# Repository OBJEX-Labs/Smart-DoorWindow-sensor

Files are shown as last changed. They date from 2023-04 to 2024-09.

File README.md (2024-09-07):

# Smart Door/Window sensor
The focus of this project is to prove how it is possible to drastically reduce the power consumption(in deep sleep/standby) of battery-powered smart devices by developing a customized power latch. Better design of smart devices would ensure a longer product life cycle.



## Power consumption

### Measurement range of PPK2
The current was measured with Nordic's power profiler kit , knowing that the current measured is less than the measurement range of this power profiler. I did several tests to verify the accuracy of the data. In any case the accuracy of the data, the consumption would be less than 200nA and this is a very good result considering that a similar device at a power consumption of 6-8uA.

### 1. Reed switch version
The consumption in deep sleep(POWER LATCH) is the same whether the magnet near the sensor or not.

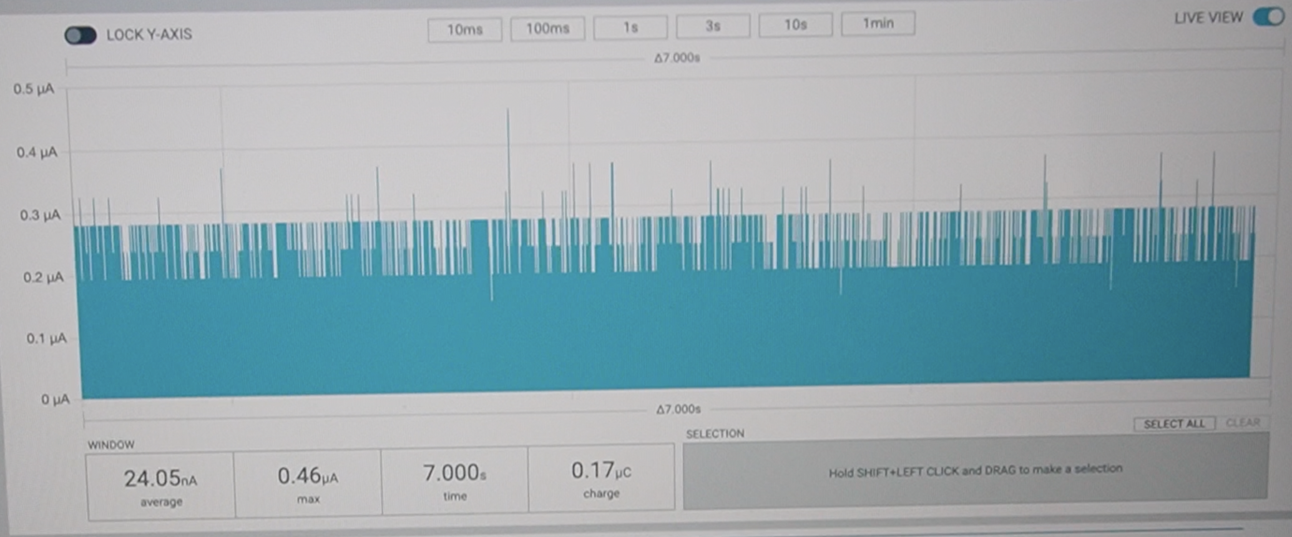
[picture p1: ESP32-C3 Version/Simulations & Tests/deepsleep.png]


### 2. MAGNETIC SENSOR IC(S-5701) version
deepsleep: 300nA

## 3D Case









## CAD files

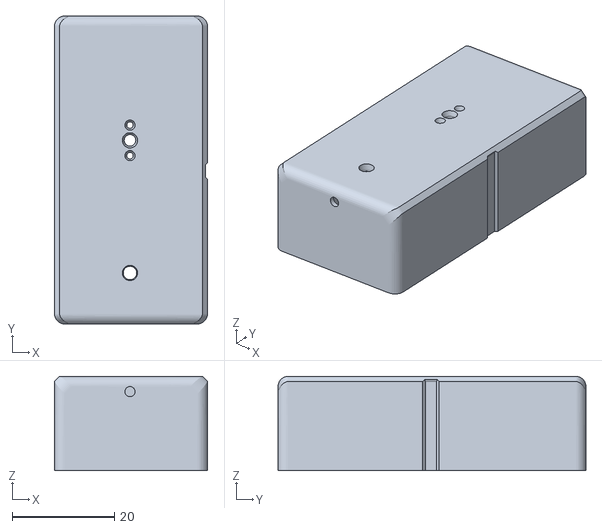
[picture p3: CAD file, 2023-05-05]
ESP32-C3 Version/3D/Outside.stl
30.0 x 60.4 x 18.5

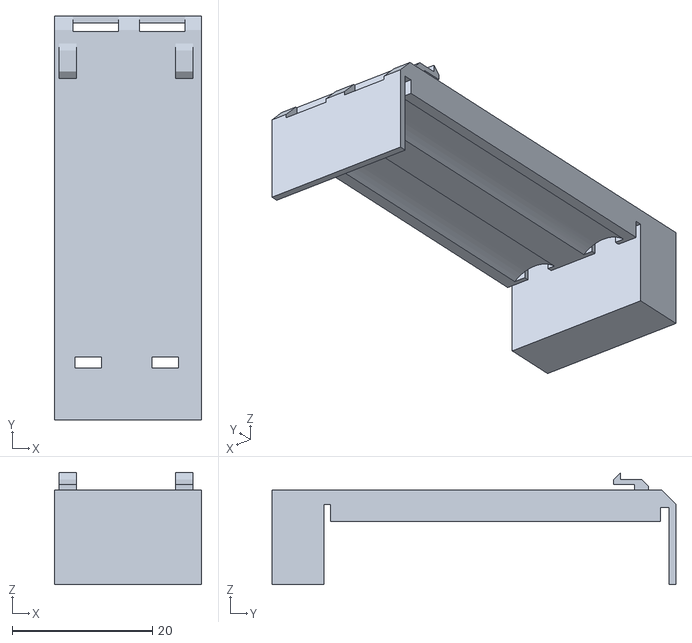
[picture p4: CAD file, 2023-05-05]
ESP32-C3 Version/3D/Inside.stl
21.0 x 57.7 x 16.0

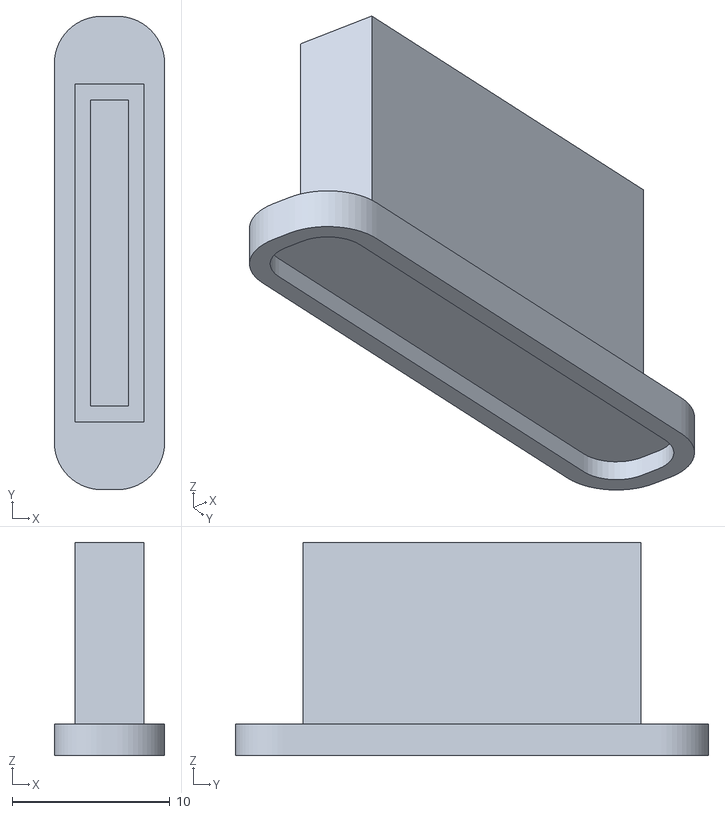
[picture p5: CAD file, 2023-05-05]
ESP32-C3 Version/3D/Bottom Magnet.stl
7.00 x 30.0 x 13.5

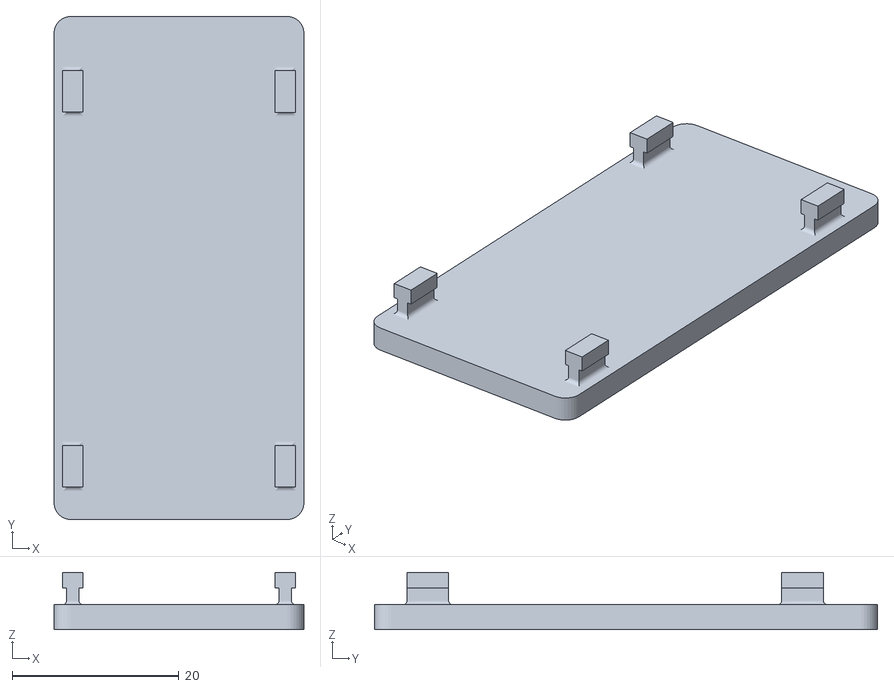
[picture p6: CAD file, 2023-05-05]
ESP32-C3 Version/3D/Bottom.stl
30.0 x 60.4 x 6.90

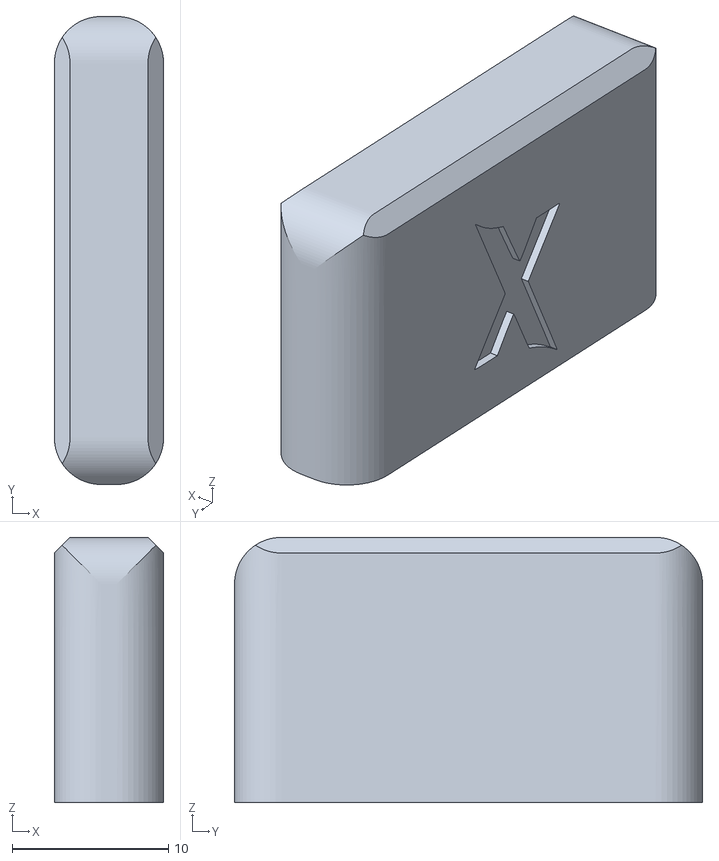
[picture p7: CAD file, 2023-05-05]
ESP32-C3 Version/3D/Magnet.stl
7.00 x 30.0 x 17.0

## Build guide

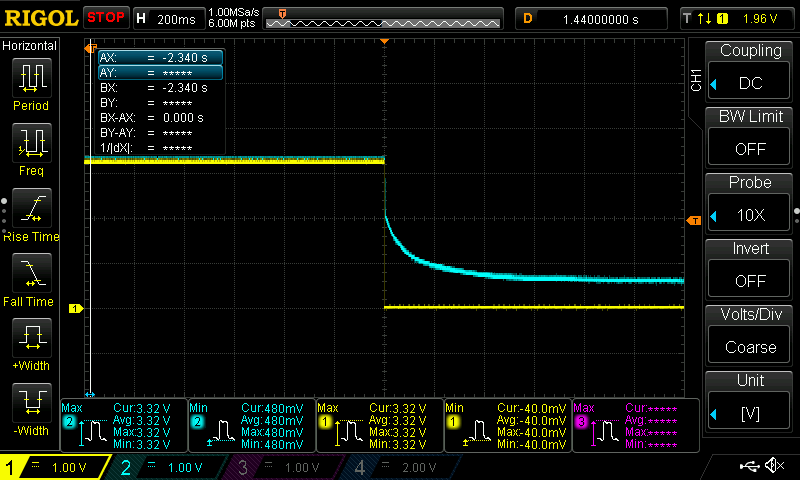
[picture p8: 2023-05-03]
ESP32-C3 Version/Simulations & Tests/DS1Z_QuickPrint24.png

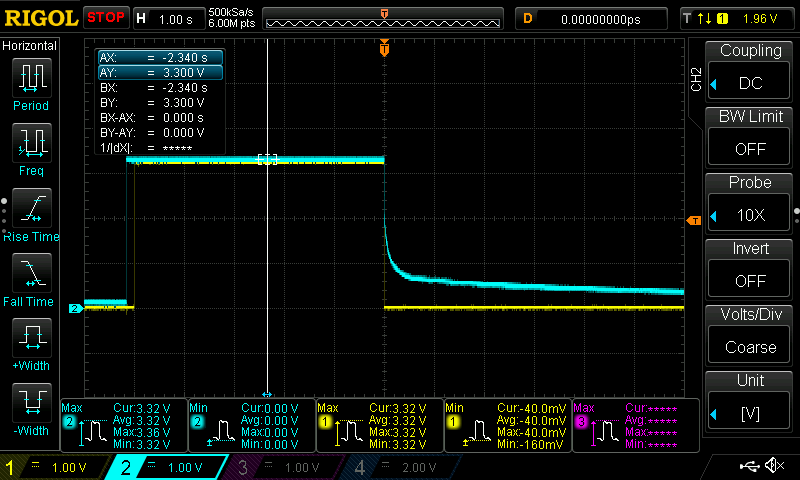
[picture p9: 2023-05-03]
ESP32-C3 Version/Simulations & Tests/DS1Z_QuickPrint27.png

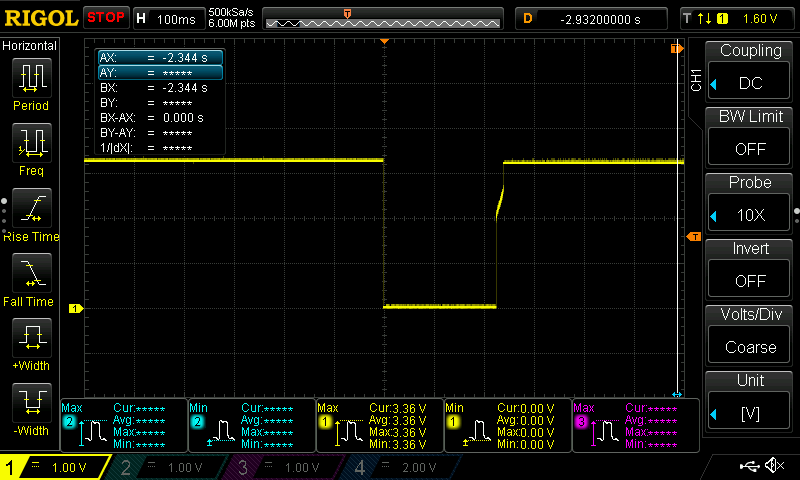
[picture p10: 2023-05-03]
ESP32-C3 Version/Simulations & Tests/DS1Z_QuickPrint20.png

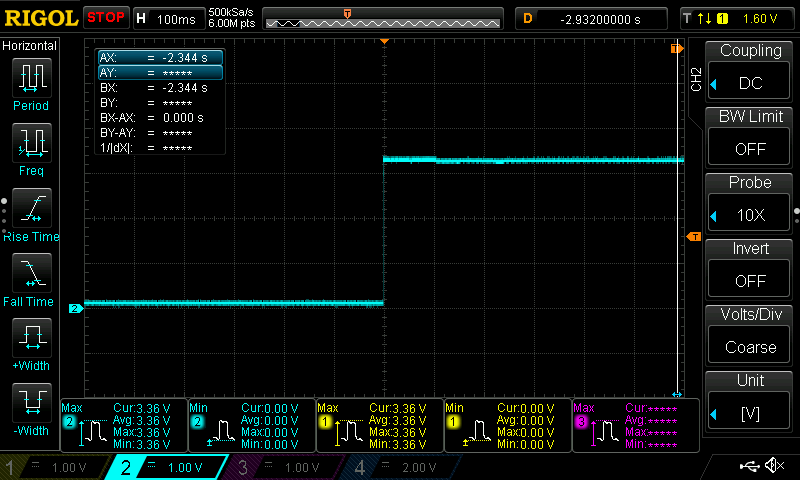
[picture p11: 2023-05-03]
ESP32-C3 Version/Simulations & Tests/DS1Z_QuickPrint21.png

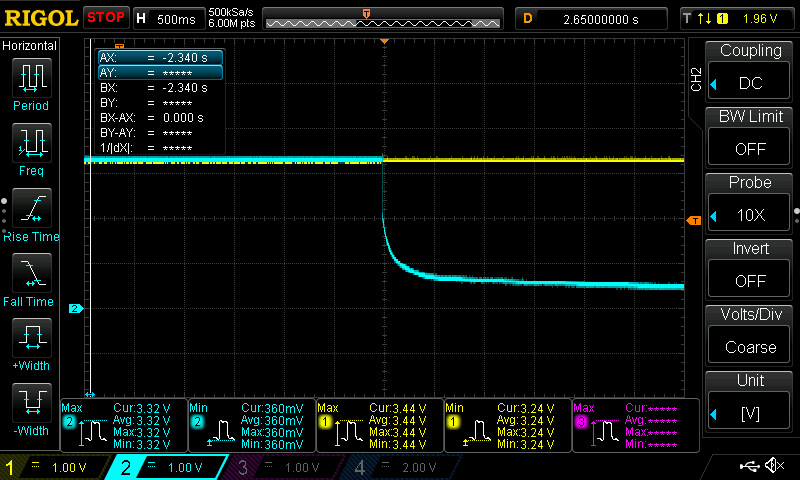
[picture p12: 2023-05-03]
ESP32-C3 Version/Simulations & Tests/DS1Z_QuickPrint22.png

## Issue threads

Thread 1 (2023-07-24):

How to add battery measurement circuit ?

Bilalembed, 2023-07-24:
Hi , can we add battery measurement circuit in this circuit to tell user the realtime battery estimation that this will take this much time. and also user should know in advance to change the battery.

Thanks

salvatoreraccardi, 2023-07-24:
There is already a circuit for measuring the battery charge level.

Closed 2023-07-24.

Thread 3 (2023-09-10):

Can Q6 and Q3 be replaced with components from other SOT-23 packaging models

zhuzhihua422619, 2023-09-10:
Can Q6 and Q3 be replaced with components from other SOT-23 packaging models? The component package you are using is too small, and which large packages can be used to replace it without affecting power consumption

salvatoreraccardi, 2023-11-19:
It depends very much on the replacement you find for the component I used.

Closed 2023-11-19.

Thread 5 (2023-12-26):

Question about Power consumption

Gafielt, 2023-12-26:
Hi Salvatore, I am very impressed by the power consumption you have achieved. I tried to understand how you got as low as 24nA, but sadly can't fully wrap my head around it. In the simulation you have provided, the numbers make sense to me (all currents for the transistors). I am only a bit sceptical about the xor chips. In the datasheet, it is said, that they would consume 10uA (which is quite a lot in your case). The resistors for detecting the switch state do also use about 400nA. Do you have any clue what I am missing or did you just had luck in the chip lottery (i guess)?

Thanks in advance! Great project!

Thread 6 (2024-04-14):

Sharing of your Smart Door / window sensor project

aeonSolutions, 2024-04-14:
Hi @salvatoreraccardi ,
great work. Been watching it on YouTube. Loved it!

Just to let you know I'm sharing your project on my own "Home automation" projects here on GitHub.
Here's the link :
[https://github.com/aeonSolutions/PCB-Prototyping-Catalogue/blob/main/Home-Automation/README.md](https://github.com/aeonSolutions/PCB-Prototyping-Catalogue/blob/main/Home-Automation/README.md)

👍

salvatoreraccardi, 2024-04-14:
Hi @aeonSolutions,
I'm glad you liked the project, that's fine for me!

aeonSolutions, 2024-04-14:
cool

since I'm here, today...

and I see you have a business as well.
On my main PCB catalog page, you can find many useful ideas on how to navigate a user from a raw repository like yours, passing by a Web interactive viewer for each PCB design and ending on an eCommerce website.

If Githuvb is your thing, I have to recommend you have a look at my "pcb catalog" and all other pages that are linked to it, here on GitHub.
Here's the direct link:

[https://github.com/aeonSolutions/PCB-Prototyping-Catalogue](https://github.com/aeonSolutions/PCB-Prototyping-Catalogue)

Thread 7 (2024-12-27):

Power the ESP directly from the NC reed switch

zorro1011, 2024-12-27:
Hi
power the ESP directly reed NC

I would like to know if there is a way to power the ESP directly using the reed NC as a simple switch.

I'm trying but it seems that the reed, once turned on (moving the magnet away), can no longer be turned off by moving the magnet closer.

I apologize if I'm OT

salvatoreraccardi, 2024-12-27:
Hi @zorro1011,
usually, it is not recommended to do this; the reed switch is not meant to have the current flowing through it to power the ESP. The idea is to use the reed switch to activate a circuit that handles the power supply to the load. I recommend you take a look at our ELPM-S3LW, you could directly connect the reed switch to the master pin. Here is a prototype we developed recently that I will show on a youtube video soon:
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

zorro1011, 2024-12-27:
thanks for answering me
the thing I don't understand is that I tried successfully to power LEDs with reed with a load greater than 200mA, but my esp32c3 that only consumes 90mA, creates problems for me with the reed

I've been fighting for days and I've tried more reeds (of the same batch and with more magnets) but without success! :-(

I thank you and I think that in the end I will have to give up and do as you say.
I was hoping that someone had succeeded

best regards

zorro1011, 2024-12-28:
Hi
for those interested, I found the problem

the esp has an electrolytic capacitor that discharges when it is not powered.
it is like a short circuit for the Reed Switch that makes the platinum points "stick".
I put a 10k resistor in parallel with the Reed that keeps the esp electrolytic charged (I measured 2V) and makes sure that when turned on the points no longer stick.

thanks to everyone and I apologize again for the OT

best regards
happy new year to everyone

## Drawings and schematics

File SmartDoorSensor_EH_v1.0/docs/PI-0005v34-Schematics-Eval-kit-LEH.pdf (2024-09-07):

## Configurations CFG (2,1,0)

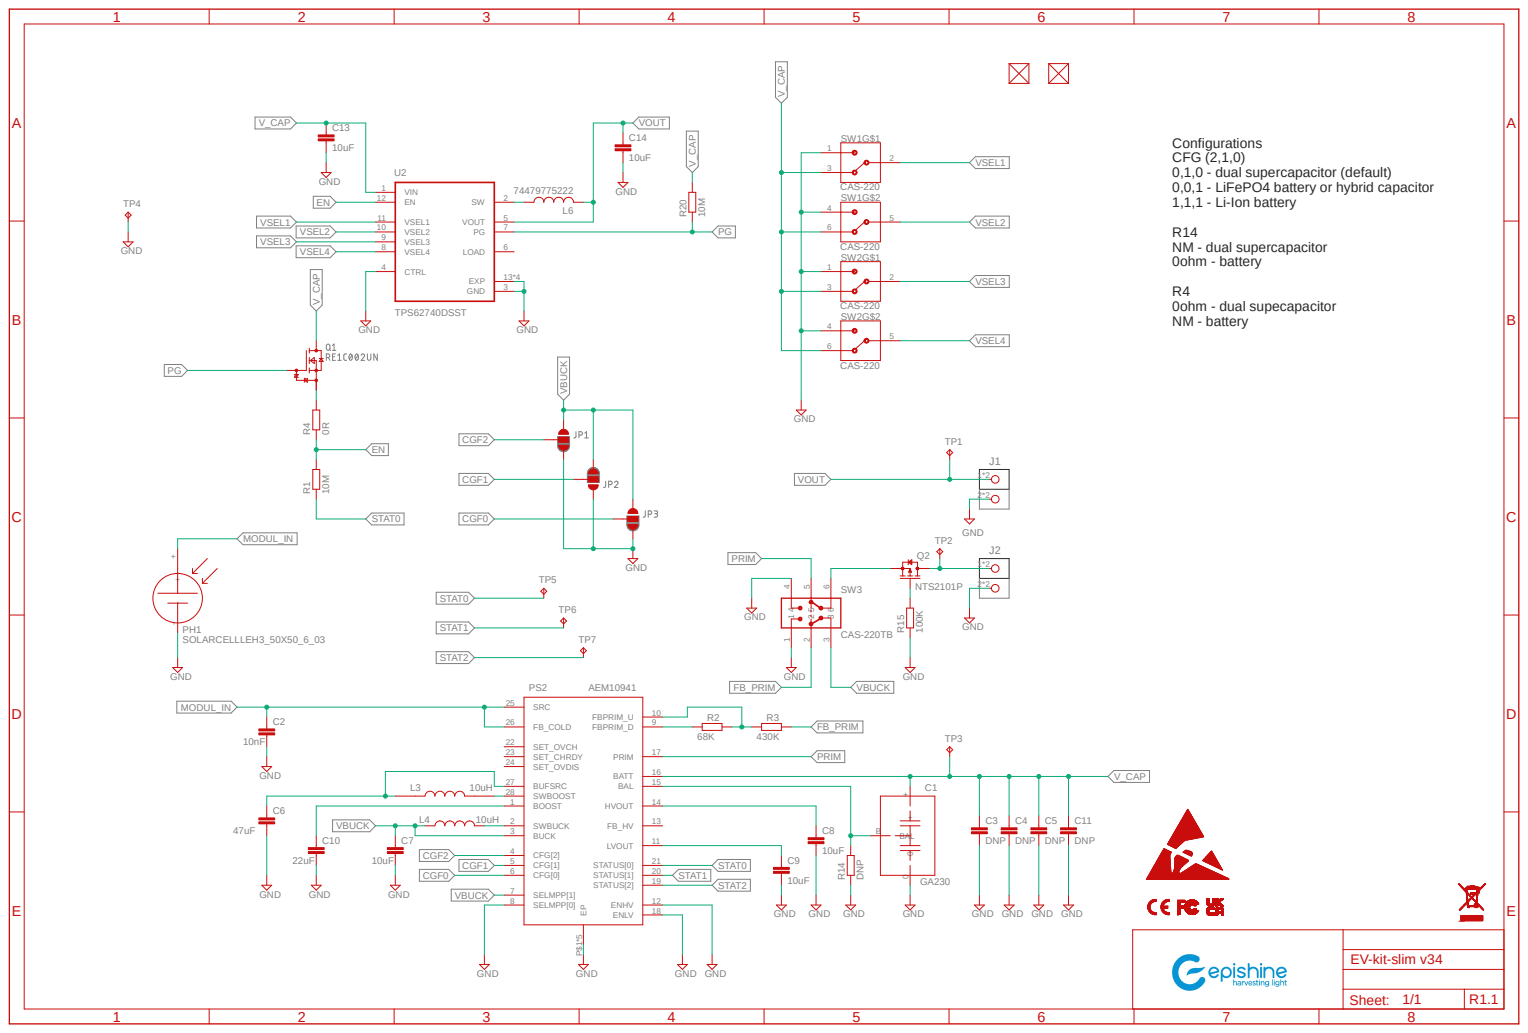
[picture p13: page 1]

0,1,0 - dual supercapacitor (default)
0,0,1 - LiFePO4 battery or hybrid capacitor
1,1,1 - Li-Ion battery

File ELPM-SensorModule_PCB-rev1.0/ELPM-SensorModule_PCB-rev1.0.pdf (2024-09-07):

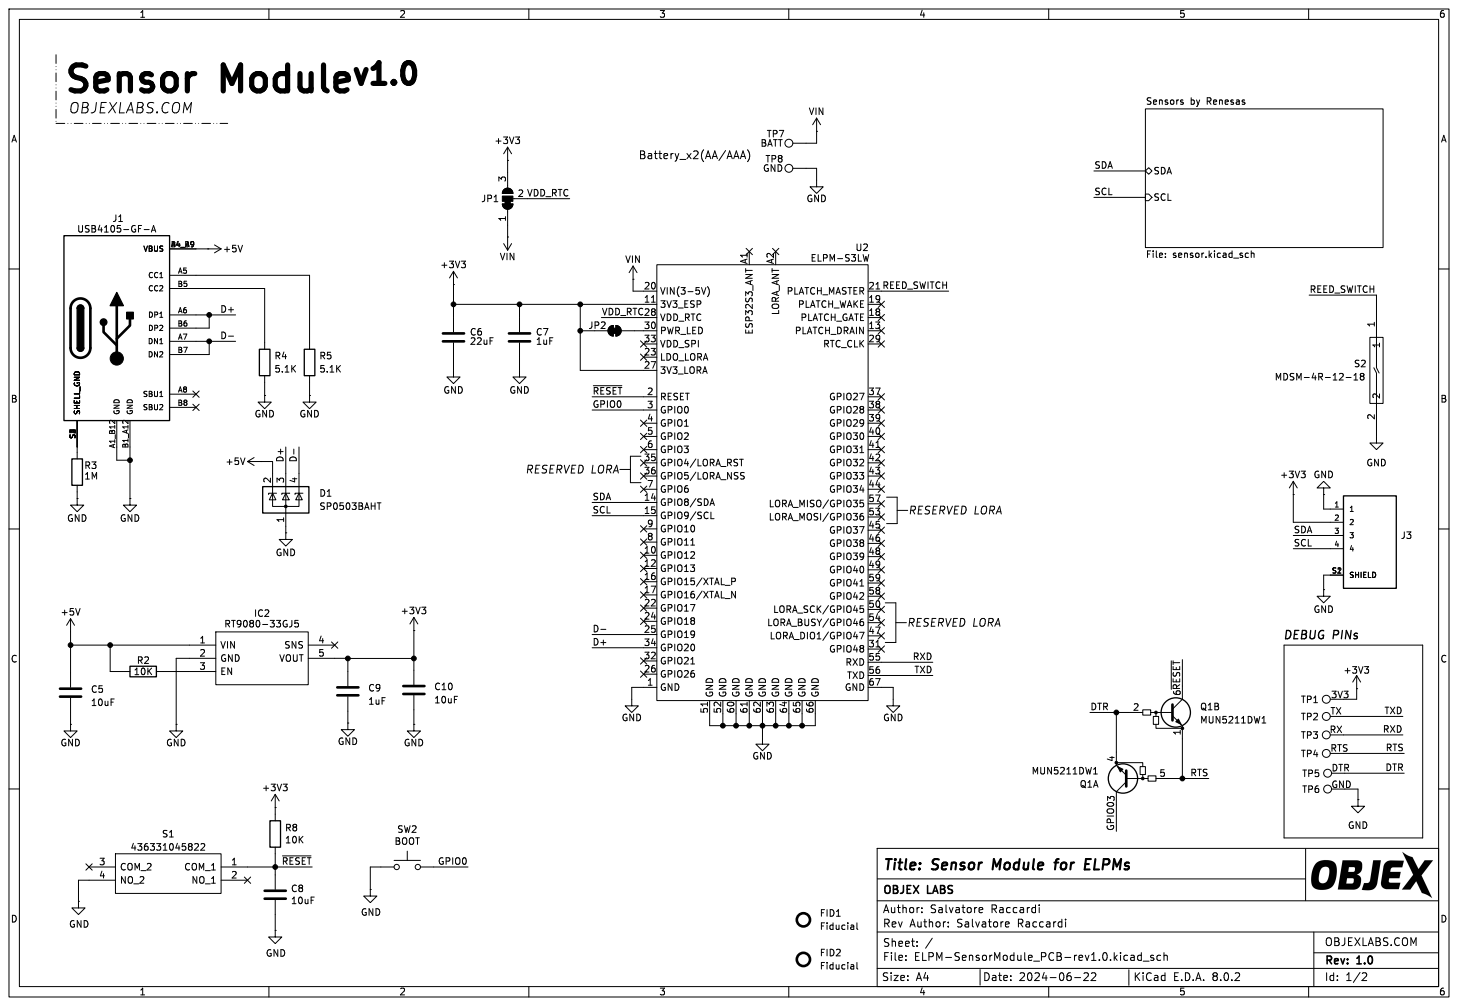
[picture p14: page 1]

RESERVED LORA OBJEXLABS.COM
VIN GND

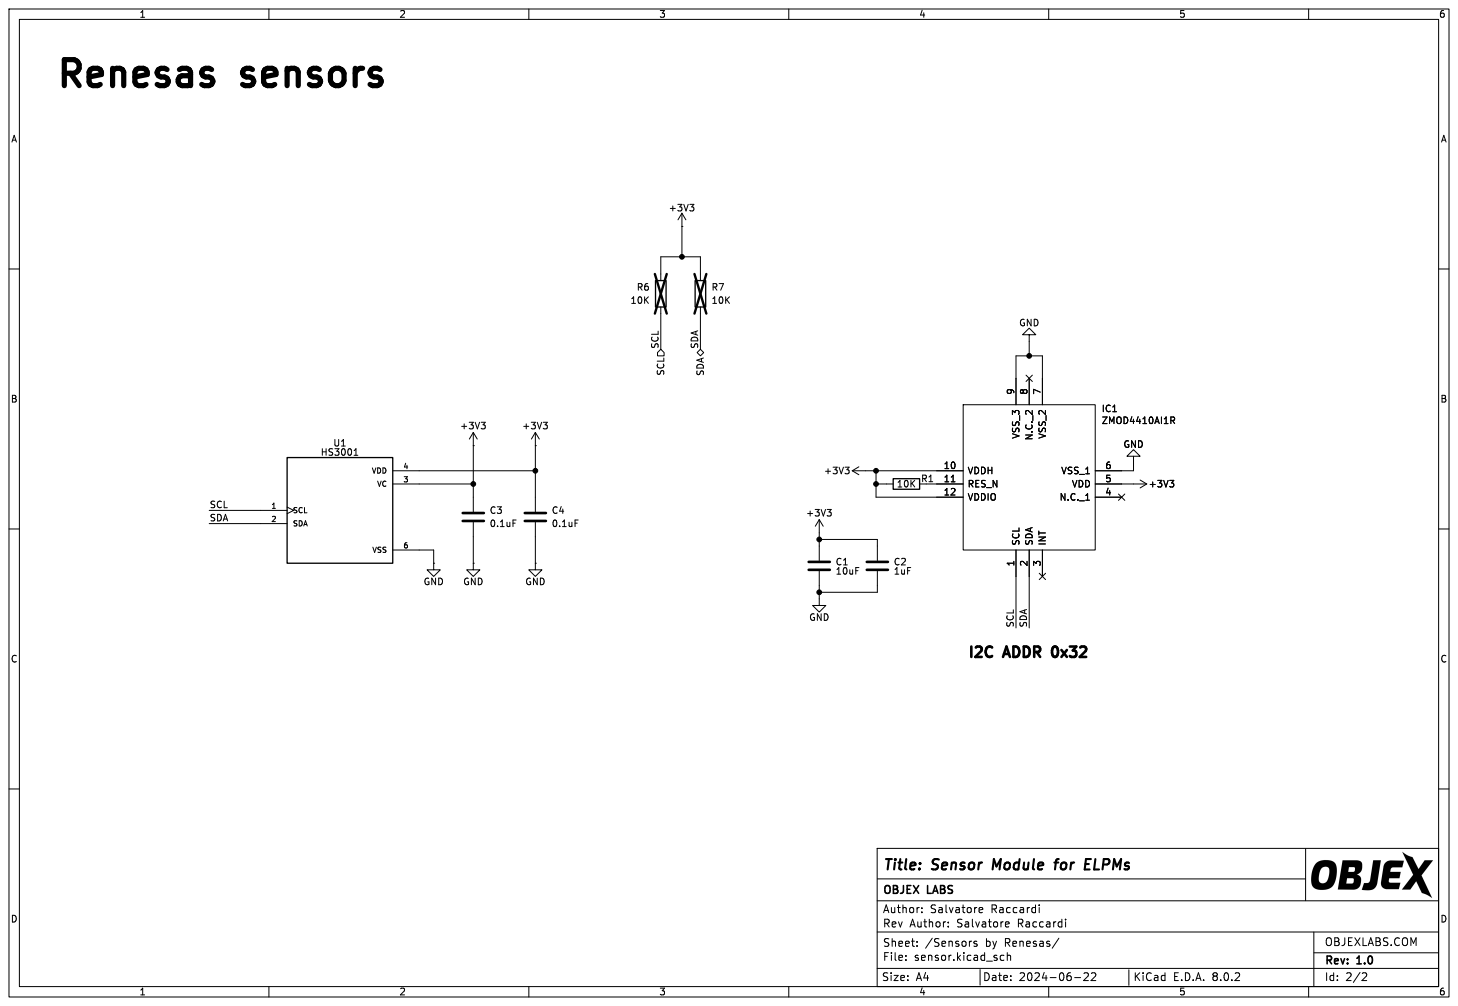
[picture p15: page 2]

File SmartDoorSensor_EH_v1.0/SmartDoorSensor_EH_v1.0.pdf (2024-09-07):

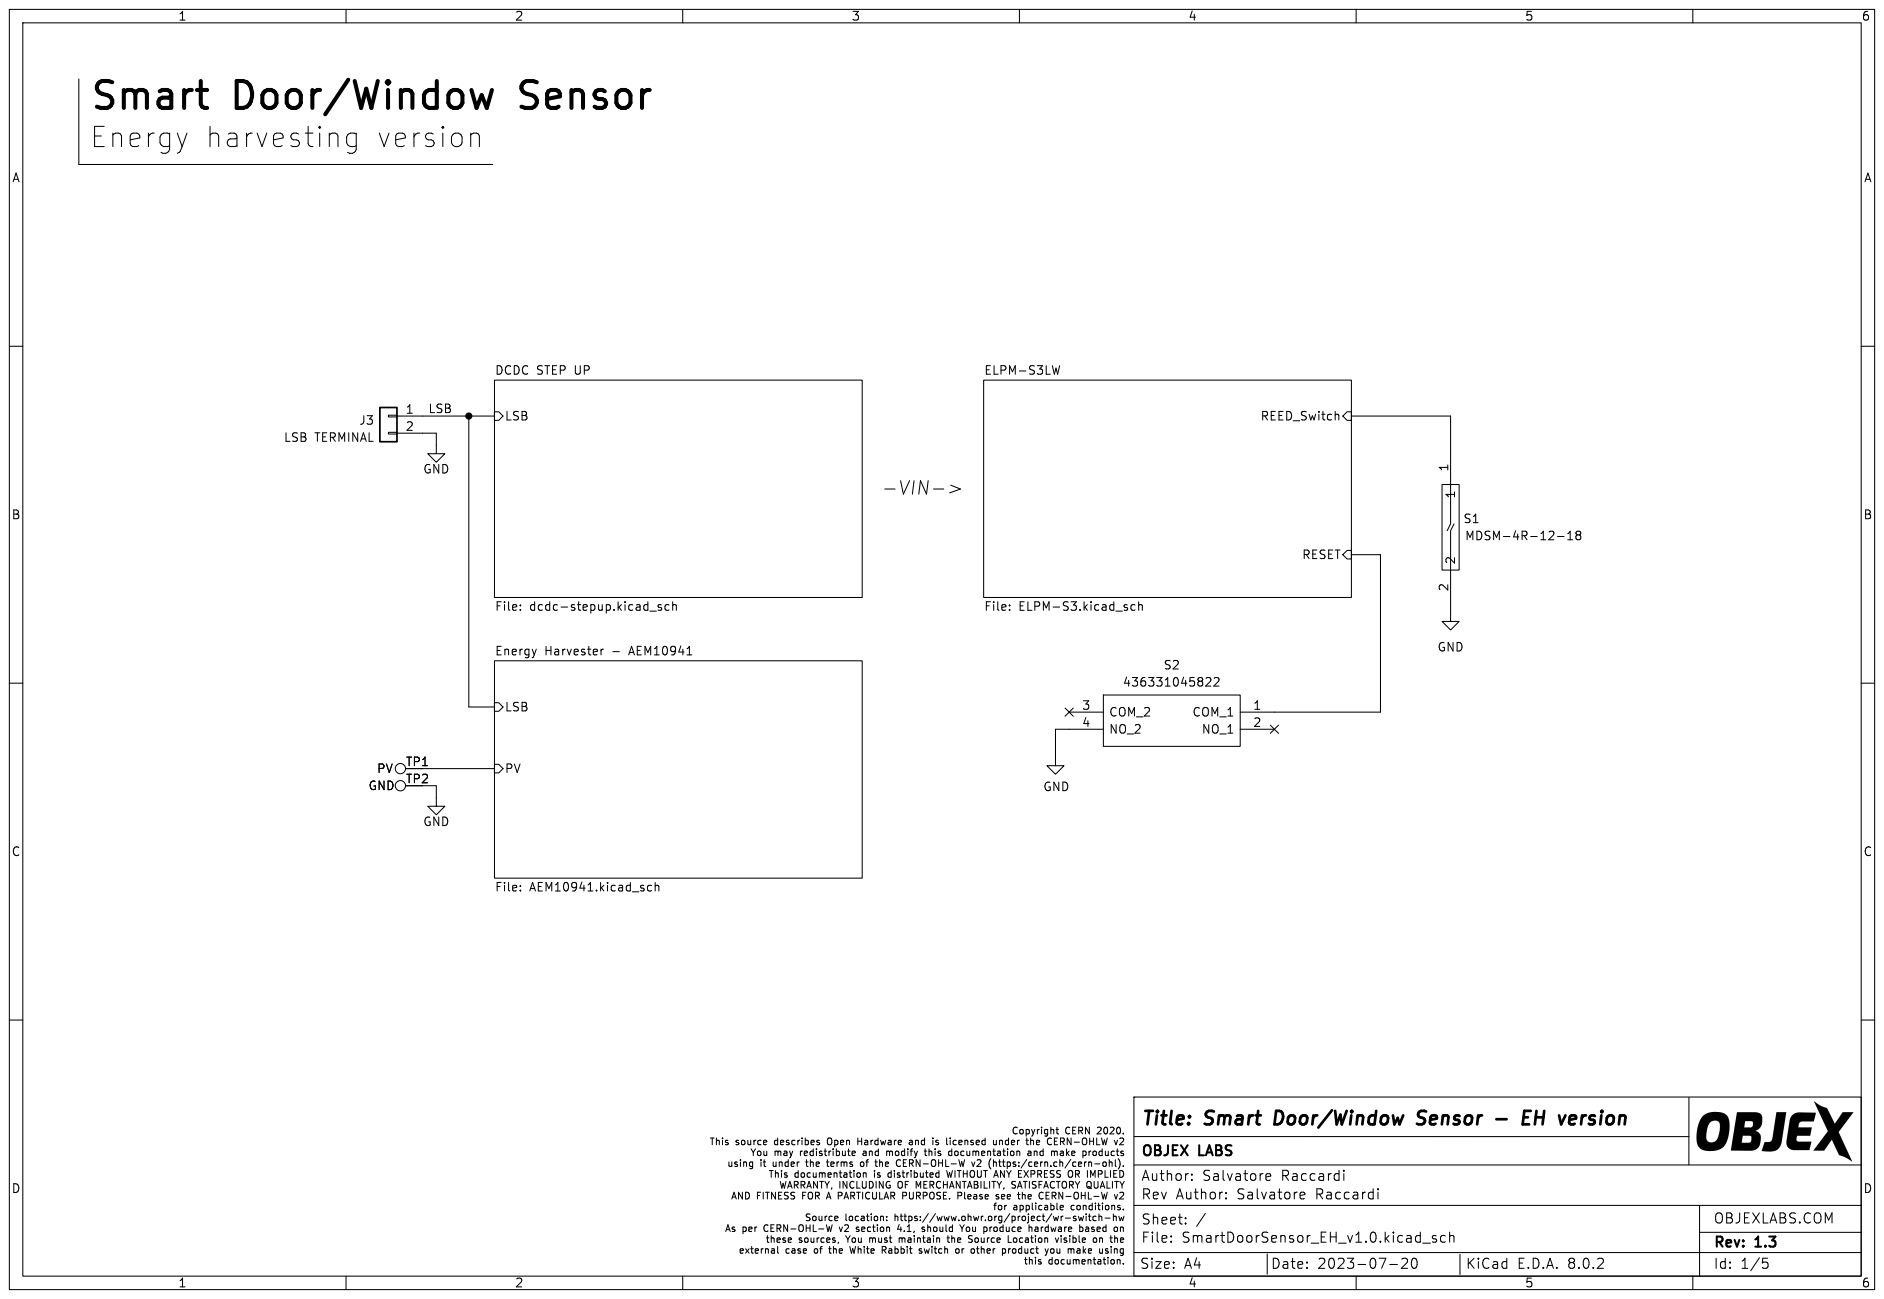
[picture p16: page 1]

Smart Door/Window Sensor

LSB DCDC STEP UP

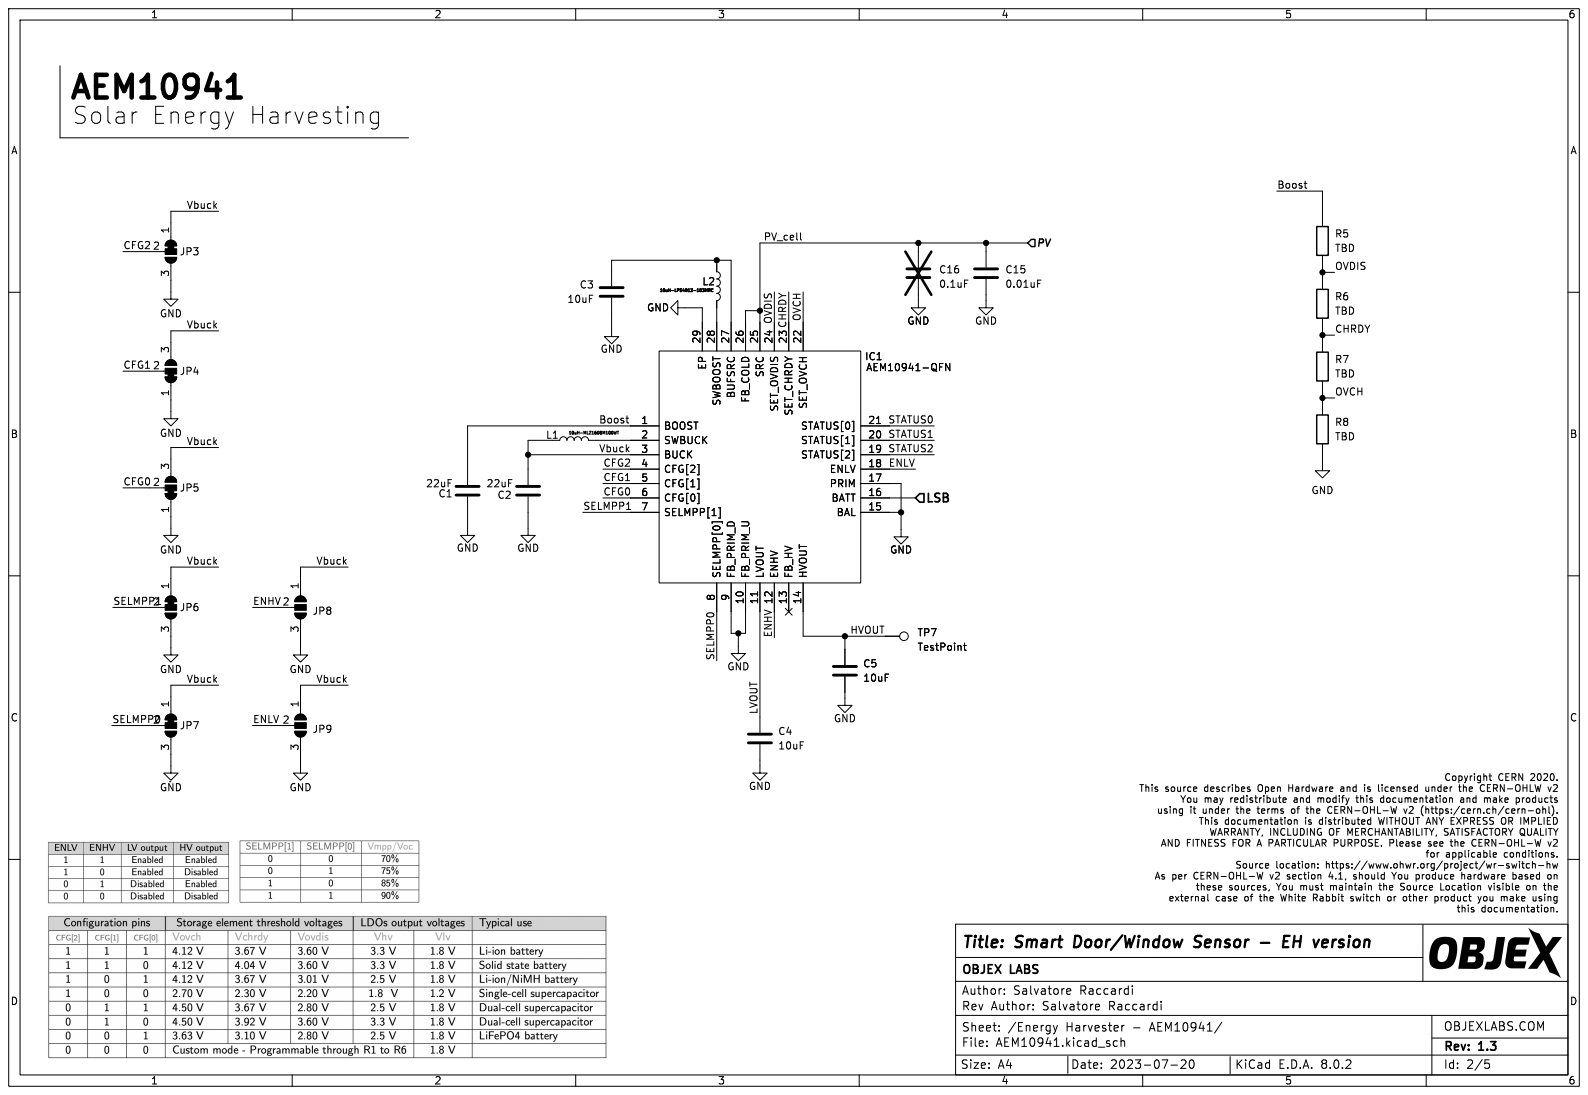
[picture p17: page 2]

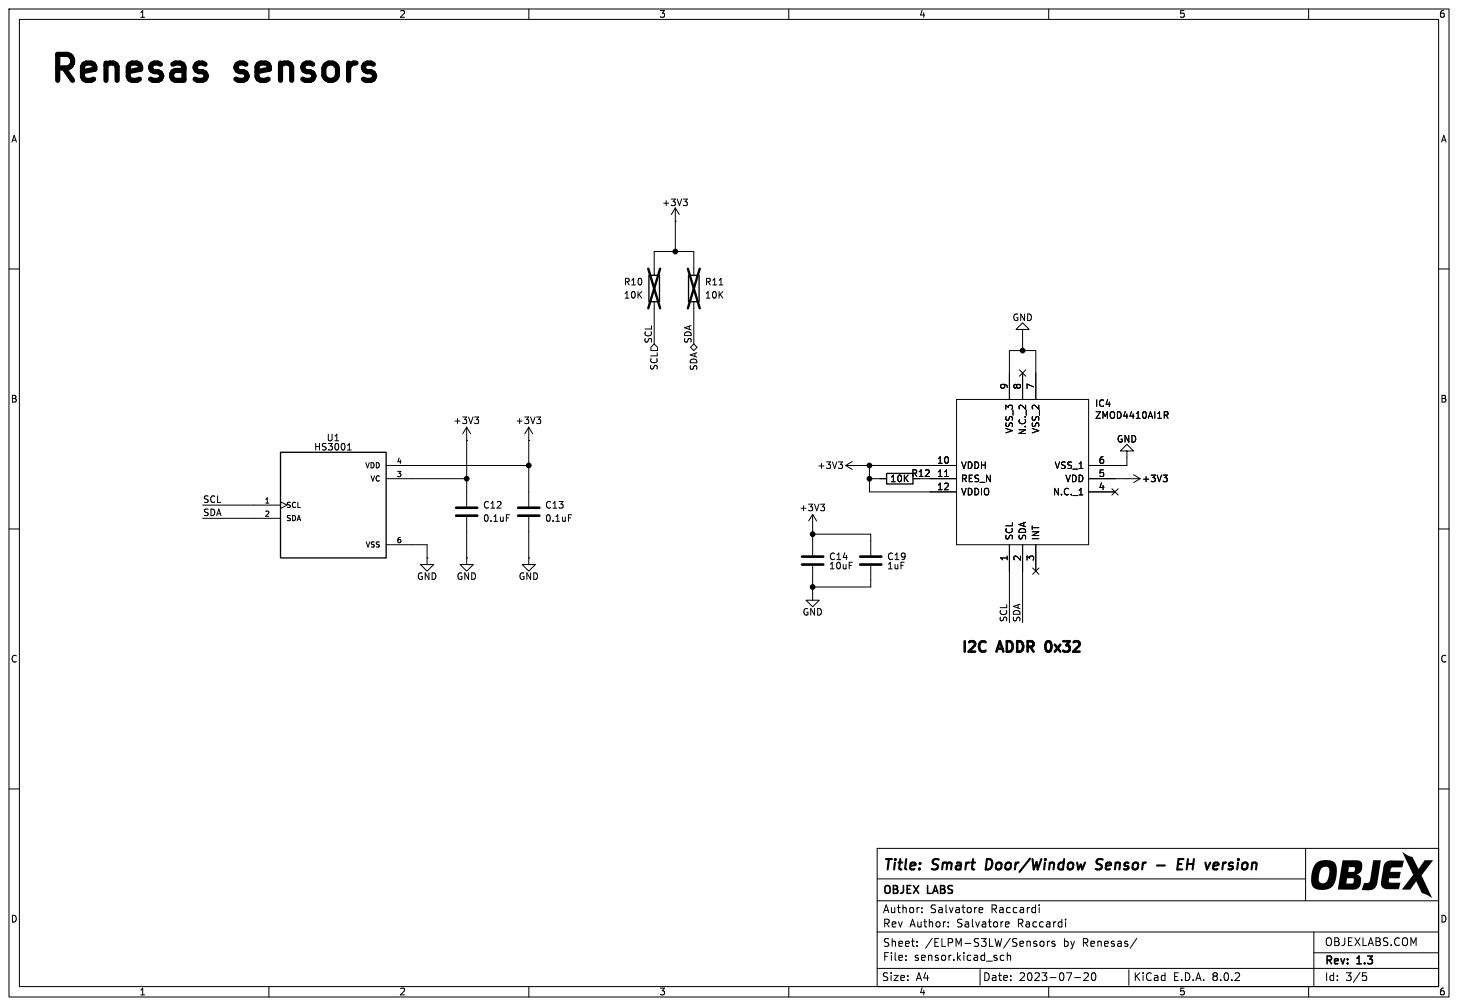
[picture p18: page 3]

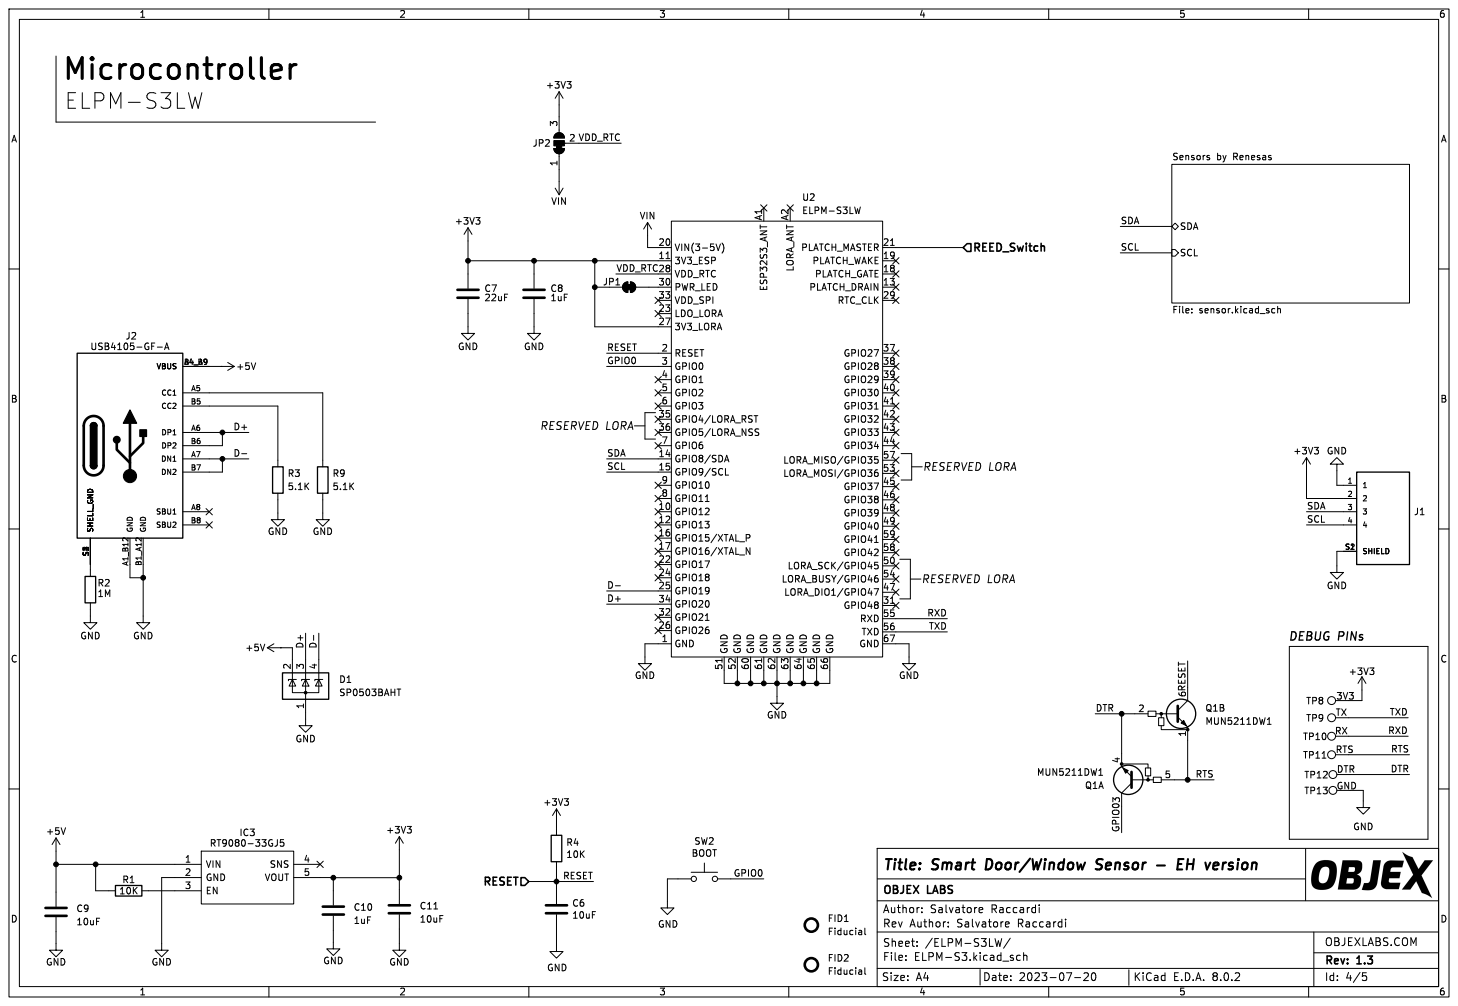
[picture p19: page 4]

Sensors by Renesas File: sensor.kicad_sch R2

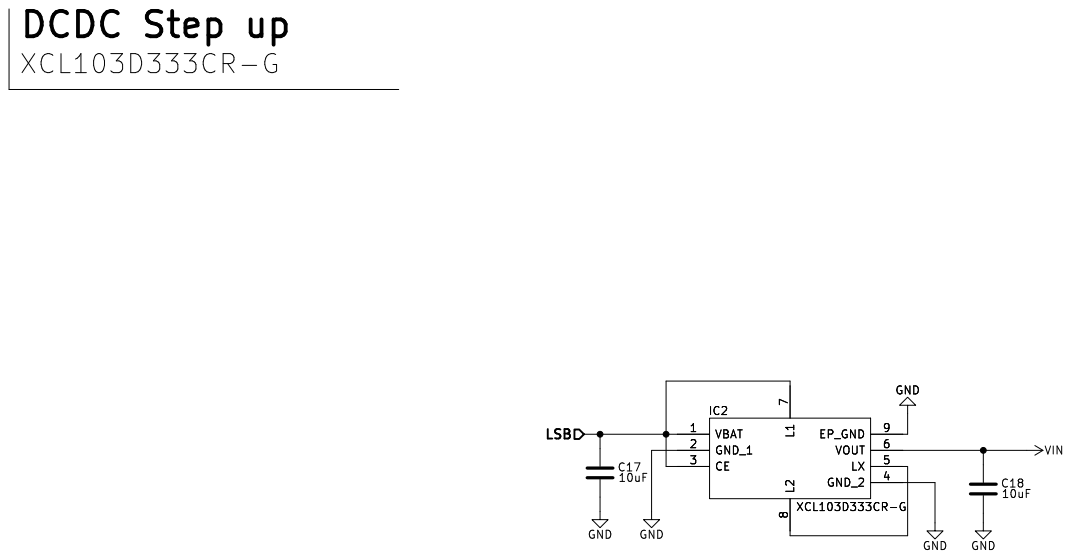
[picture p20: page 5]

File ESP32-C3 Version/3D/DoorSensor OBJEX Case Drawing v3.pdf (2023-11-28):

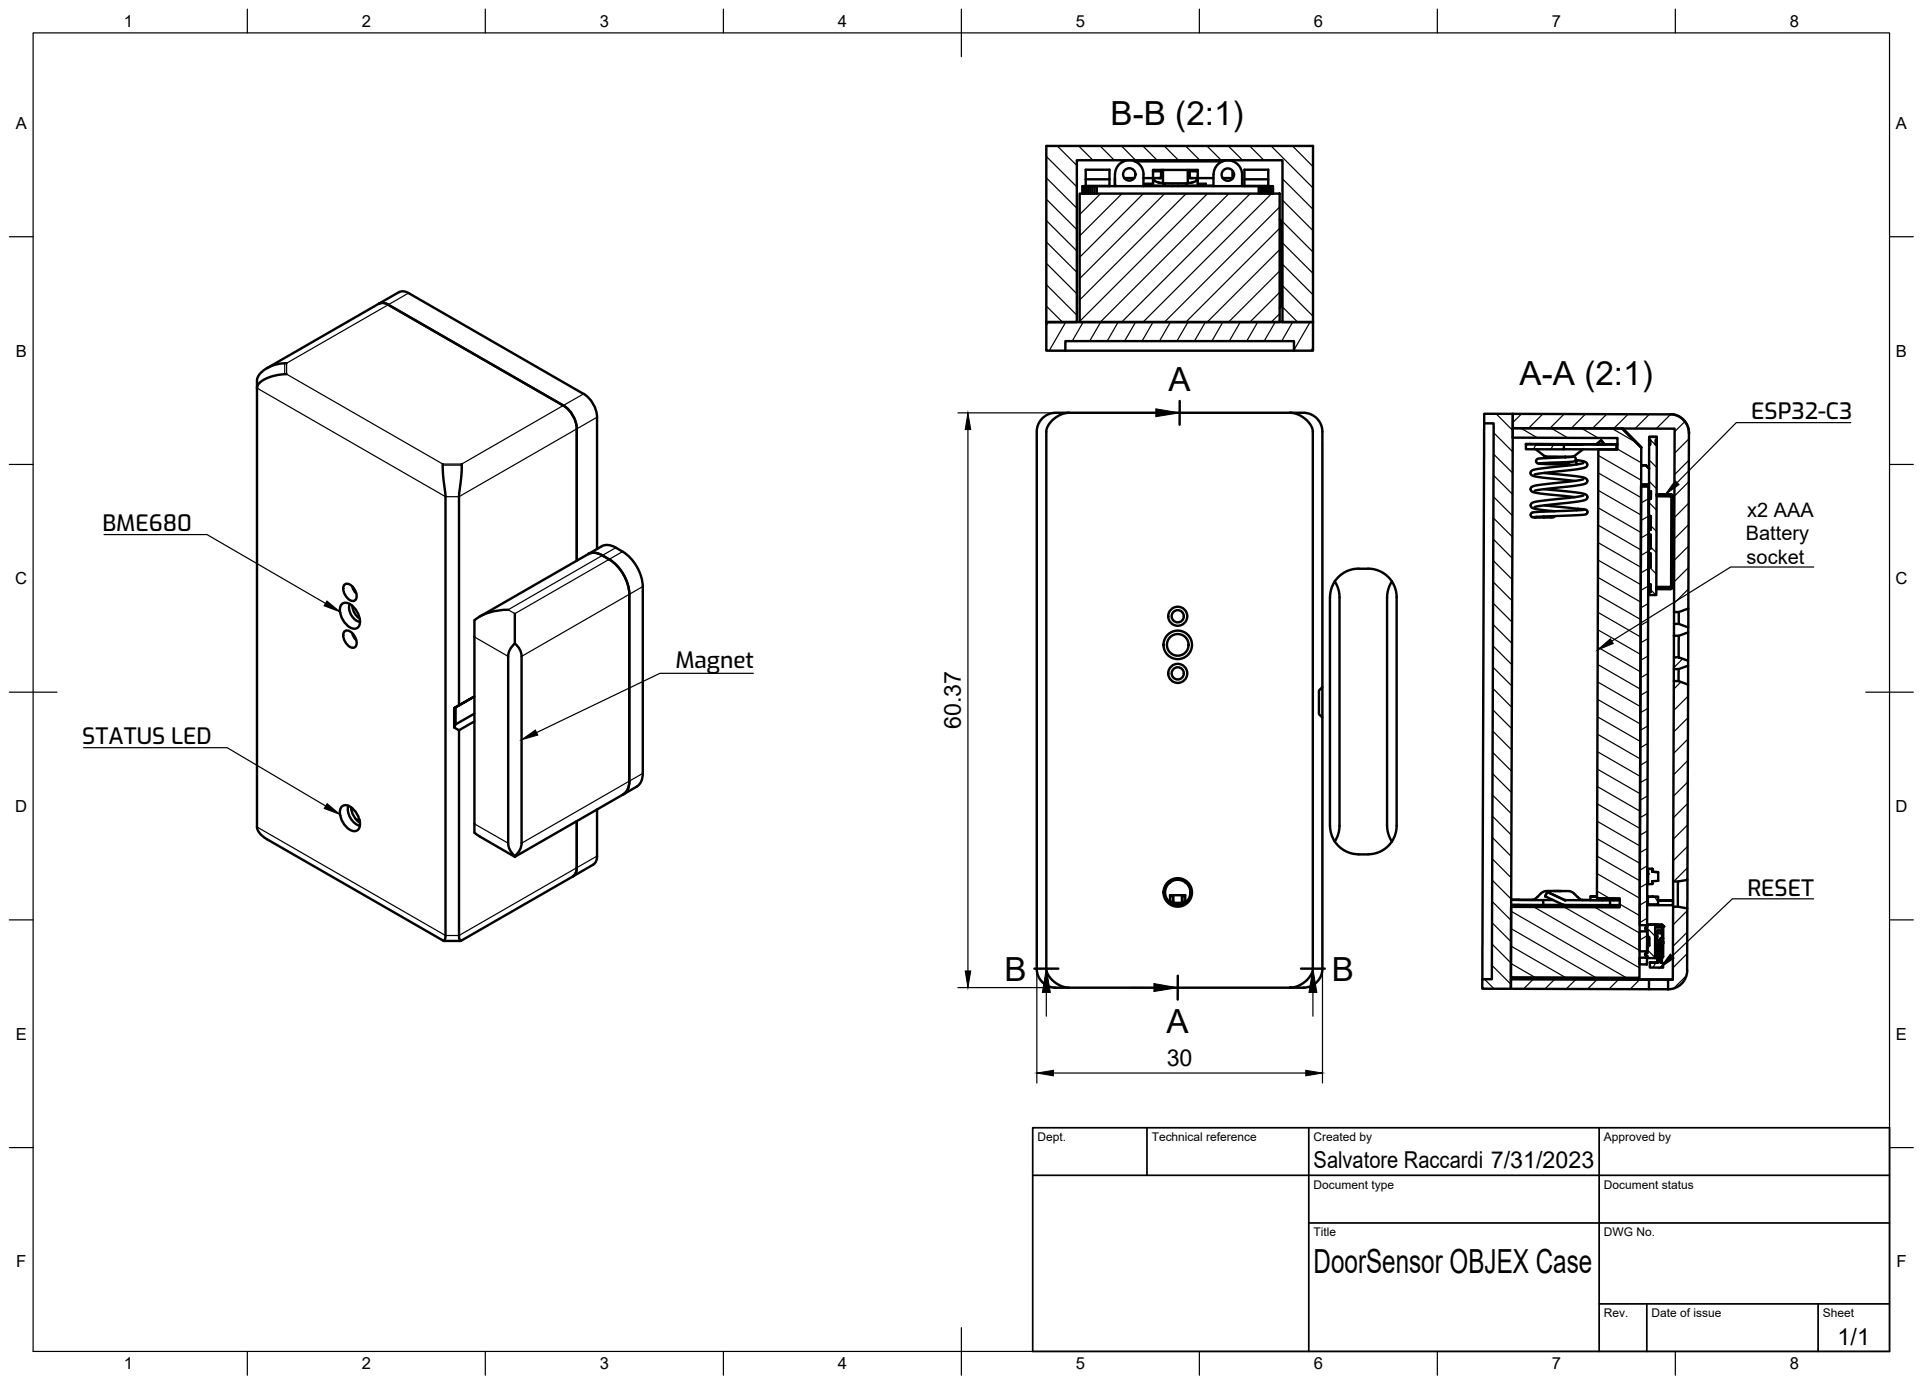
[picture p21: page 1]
Title; DWG No.; Rev.; Date of issue; Sheet; STATUS LED; x2 AAA

Dept. | Technical reference | Created by Salvatore Raccardi 7/31/2023 | Approved by

Document type | Document status

DoorSensor OBJEX Case

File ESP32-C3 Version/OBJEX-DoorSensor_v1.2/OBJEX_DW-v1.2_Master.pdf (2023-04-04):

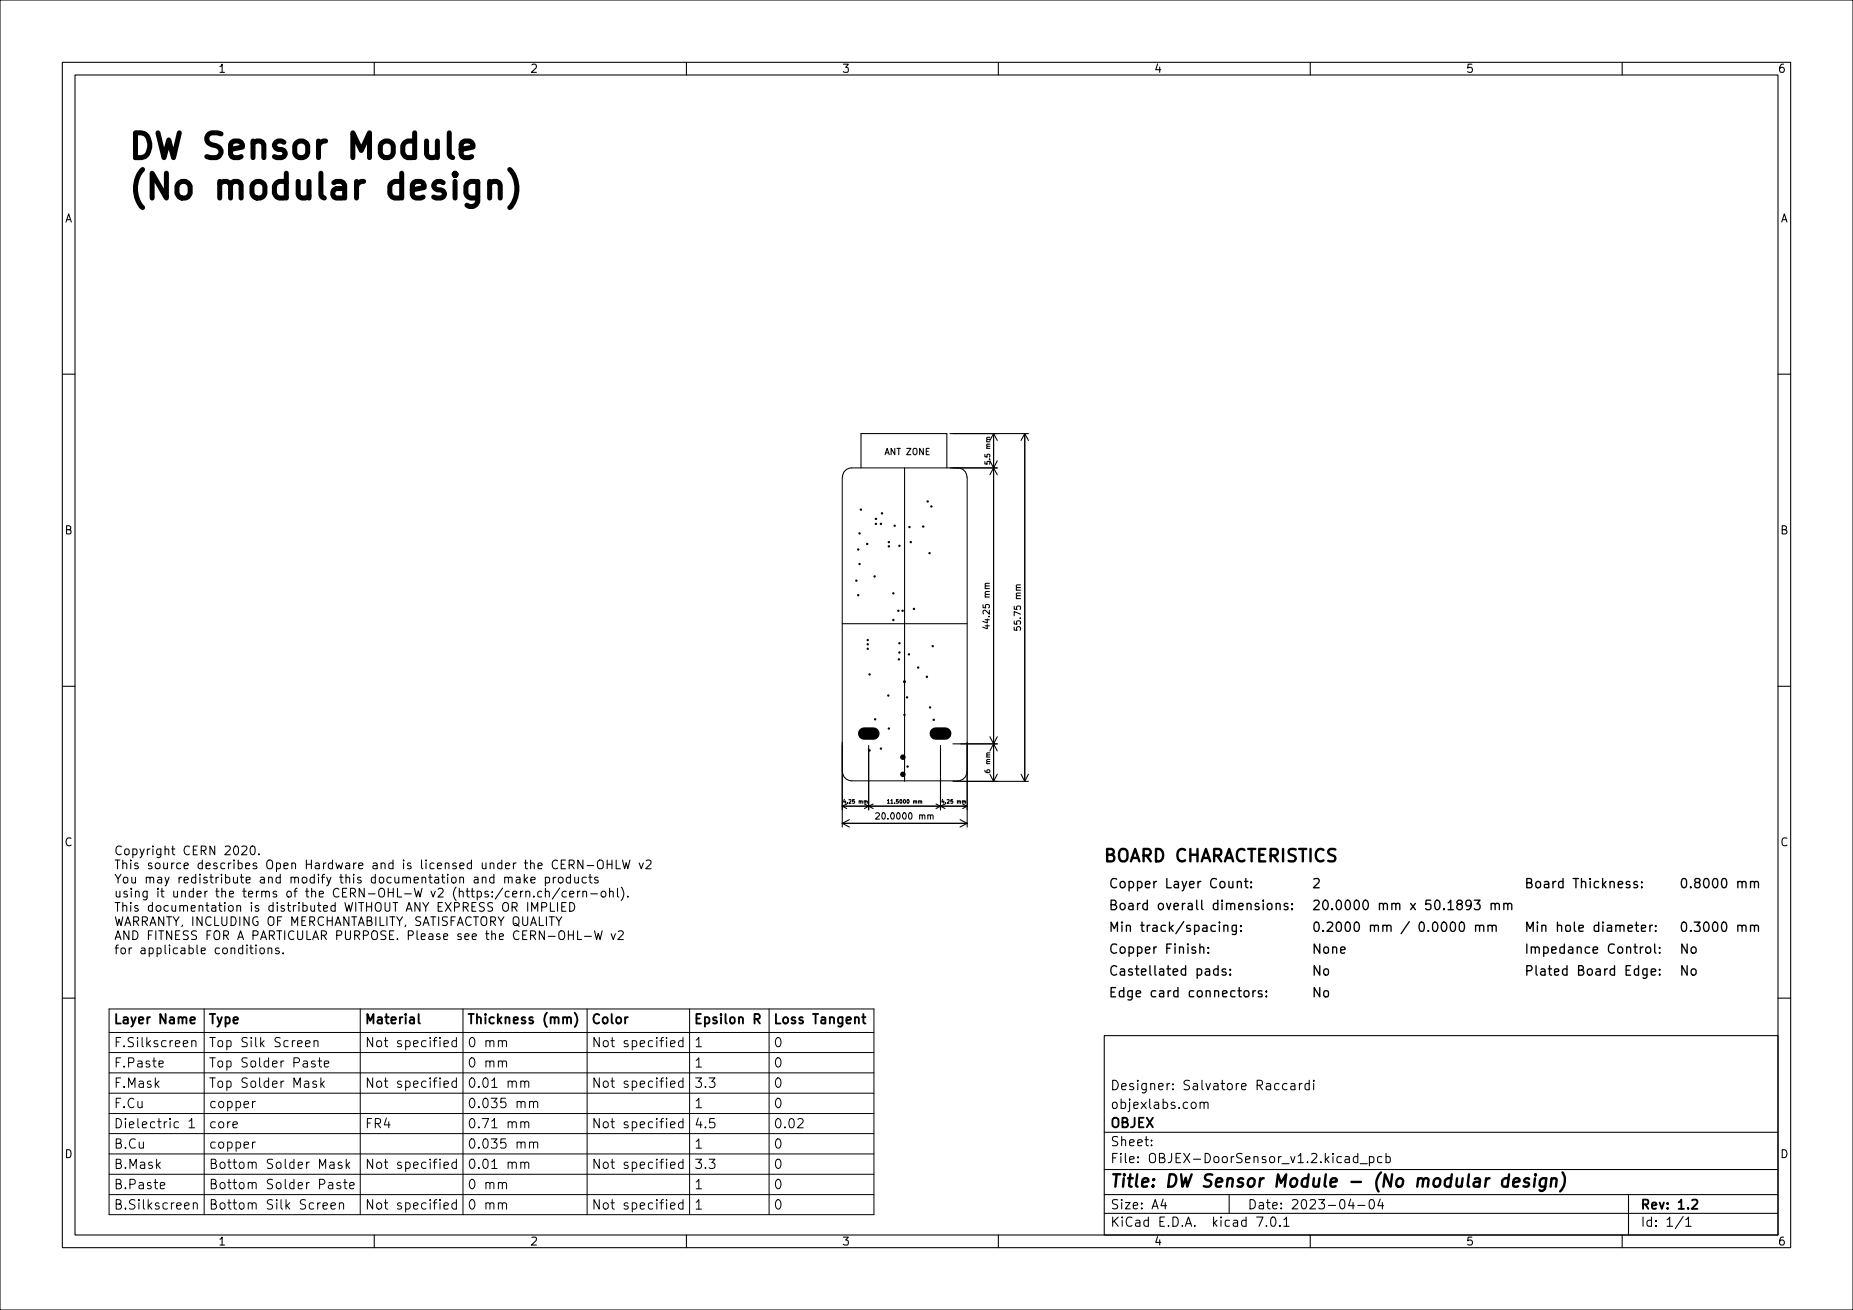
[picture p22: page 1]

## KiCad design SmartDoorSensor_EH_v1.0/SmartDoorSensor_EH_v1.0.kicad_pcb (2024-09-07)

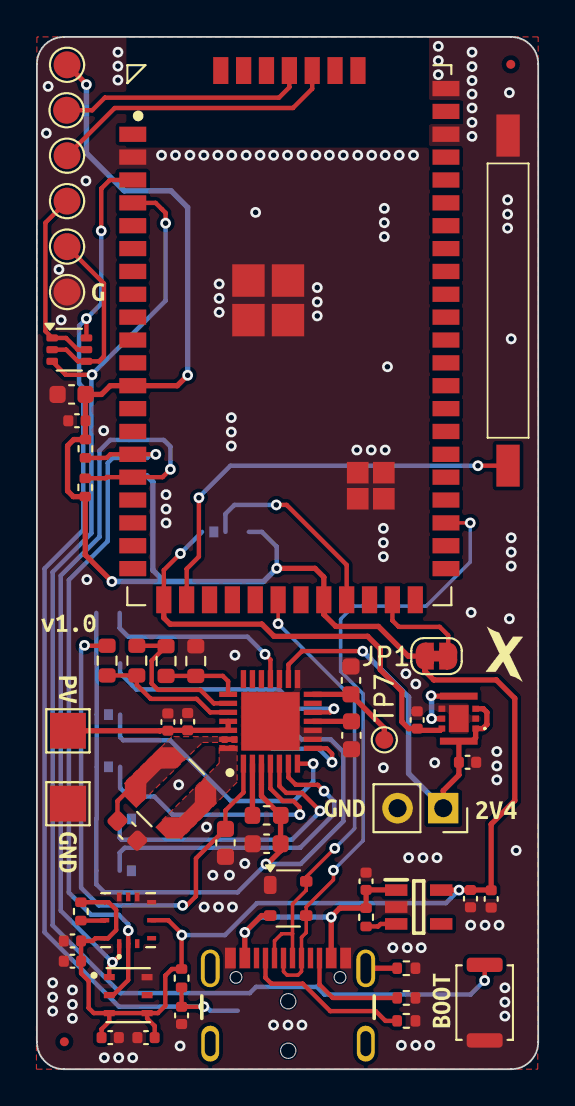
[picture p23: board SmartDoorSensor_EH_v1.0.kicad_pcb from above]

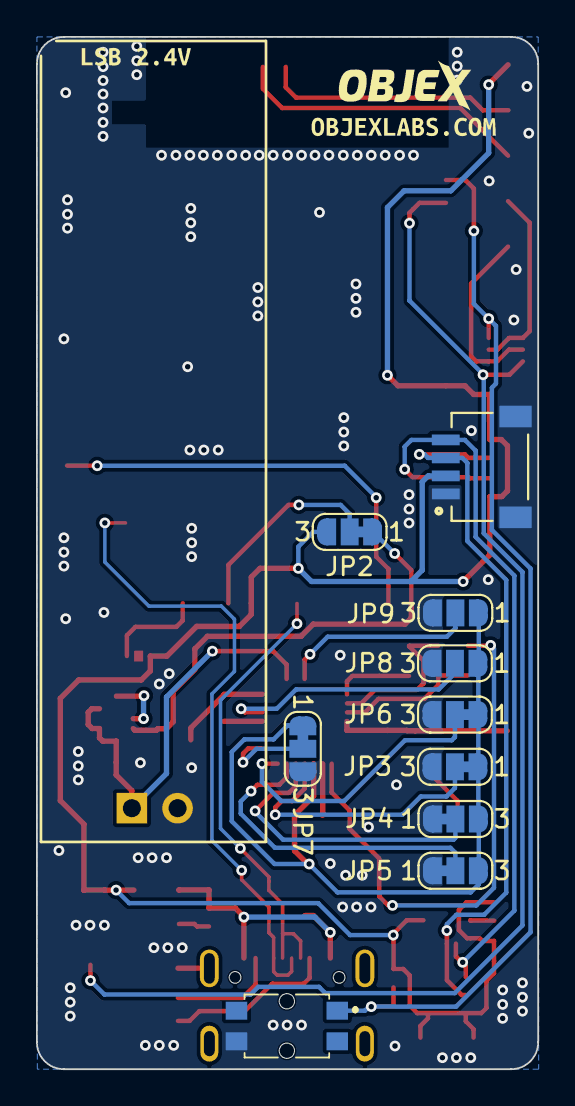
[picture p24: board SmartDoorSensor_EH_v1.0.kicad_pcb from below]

Board: 2 copper layers, 27.8 x 57.4 mm, 76 parts (12 on the bottom side), 42 nets.

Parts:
C1, C2, C7: 22uF; C_0603_1608Metric
C3, C4, C5: 10uF; C_0603_1608Metric
C6, C9, C11, C14, C17, C18: 10uF; C_0402_1005Metric
C8, C10, C19: 1uF; C_0402_1005Metric
C12, C13, C16: 0.1uF; C_0402_1005Metric
C15: 0.01uF; C_0402_1005Metric
D1: SP0503BAHT; SOT-143
FID1, FID2: Fiducial; Fiducial_0.5mm_Mask1mm
IC1: AEM10941-QFN; QFN50P500X500X90-29N-D
IC2: XCL103D333CR-G; XCL102D283CRG
IC3: RT9080-33GJ5; SOT94P280X100-5N
IC4: ZMOD4410AI1R
J1: SM04B-SRSS-TB(LF)(SN); JST_SM04B-SRSS-TB(LF)(SN)
J2: USB4105-GF-A; GCT_USB4105-GF-A
J3: LSB TERMINAL; PinSocket_1x02_P2.54mm_Vertical
JP1: SolderJumper_2_Bridged; SolderJumper-2_P1.3mm_Bridged_RoundedPad1.0x1.5mm
JP2, JP3, JP4, JP5, JP6, JP7: SolderJumper_3_Bridged12; SolderJumper-3_P1.3mm_Bridged12_RoundedPad1.0x1.5mm_NumberL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
JP8, JP9: SolderJumper_3_Open; SolderJumper-3_P1.3mm_Open_RoundedPad1.0x1.5mm_NumberLabels
L1: 10uH-MLZ1608M100WT; L_0603_1608Metric
L2: 10uH-LPS4012-103MRC; L_Coilcraft_LPS4018
Q1: MUN5211DW1; SOT-363_SC-70-6
R1, R4, R10, R11, R12: 10K; R_0402_1005Metric
R2: 1M; R_0402_1005Metric
R3, R9: 5.1K; R_0402_1005Metric
R5, R6, R7, R8: TBD; R_0603_1608Metric
S1: MDSM-4R-12-18; MDSM4R1218
S2: 436331045822
SW2: BOOT; SW_Push_SPST_NO_Alps_SKRK
TP1: PV; TestPoint_Pad_2.0x2.0mm
TP2: GND; TestPoint_Pad_2.0x2.0mm
TP7: TestPoint; TestPoint_Pad_D1.0mm
TP8: 3V3; TestPoint_Pad_D1.5mm
TP9: TX; TestPoint_Pad_D1.5mm
TP10: RX; TestPoint_Pad_D1.5mm
TP11: RTS; TestPoint_Pad_D1.5mm
TP12: DTR; TestPoint_Pad_D1.5mm
TP13: GND; TestPoint_Pad_D1.5mm
U1: HS3001; XDCR_HS3001
U2: ELPM-S3LW; ELPM-S3XX
kibuzzard-64D611C7: G***; kibuzzard-64D611C7
kibuzzard-667E7E0B: G***; kibuzzard-667E7E0B
kibuzzard-667E7E21, kibuzzard-667E7E21#2: G***; kibuzzard-667E7E21
kibuzzard-667E7EB7: G***; kibuzzard-667E7EB7
kibuzzard-667E862E: G***; kibuzzard-667E862E
kibuzzard-667956CB: G***; kibuzzard-667956CB
kibuzzard-667957A8: G***; kibuzzard-667957A8
kibuzzard-66795660: G***; kibuzzard-66795660

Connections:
+3V3: C7.1, C8.1, C10.1, C11.1, C12.1, C13.1, C14.1, C19.1, IC3.5 (VOUT), IC4.5 (VDD), IC4.10 (VDDH), IC4.12 (VDDIO), J1.2, JP1.1 (A), JP2.3 (B), R4.1, R10.1, R11.1, R12.1, TP8.1, U1.3 (VC), U1.4 (VDD), U2.11 (3V3_ESP), U2.27 (3V3_LORA)
+5V: C9.1, D1.2 (K), IC3.1 (VIN), J2.A4_B9 (VBUS), J2.B4_A9 (VBUS), R1.1
/ELPM-S3LW/D+: D1.3 (K), J2.A6 (DP1), J2.B6 (DP2), U2.34 (GPIO20)
/ELPM-S3LW/D-: D1.4 (K), J2.A7 (DN1), J2.B7 (DN2), U2.25 (GPIO19)
/ELPM-S3LW/DTR: Q1.2 (B2), Q1.4 (E1), TP12.1
/ELPM-S3LW/GPIO0: Q1.3 (C1), SW2.2, U2.3 (GPIO0)
/ELPM-S3LW/REED_Switch: S1.1, U2.21 (PLATCH_MASTER)
/ELPM-S3LW/RESET: C6.1, Q1.6 (C2), R4.2, S2.1 (COM_1), U2.2 (RESET)
/ELPM-S3LW/RTS: Q1.1 (E2), Q1.5 (B1), TP11.1
/ELPM-S3LW/RXD: TP10.1, U2.55 (RXD)
/ELPM-S3LW/SCL: IC4.1 (SCL), J1.4, R10.2, U1.1 (SCL), U2.15 (GPIO9/SCL)
/ELPM-S3LW/SDA: IC4.2 (SDA), J1.3, R11.2, U1.2 (SDA), U2.14 (GPIO8/SDA)
/ELPM-S3LW/TXD: TP9.1, U2.56 (TXD)
/ELPM-S3LW/VDD_RTC: JP2.2 (C), U2.28 (VDD_RTC)
/Energy Harvester - AEM10941/Boost: C1.2, IC1.1 (BOOST), R5.1
/Energy Harvester - AEM10941/CFG0: IC1.6 (CFG[0]), JP5.2 (C)
/Energy Harvester - AEM10941/CFG1: IC1.5 (CFG[1]), JP4.2 (C)
/Energy Harvester - AEM10941/CFG2: IC1.4 (CFG[2]), JP3.2 (C)
/Energy Harvester - AEM10941/CHRDY: IC1.23 (SET_CHRDY), R6.2, R7.1
/Energy Harvester - AEM10941/ENHV: IC1.12 (ENHV), JP8.2 (C)
/Energy Harvester - AEM10941/ENLV: IC1.18 (ENLV), JP9.2 (C)
/Energy Harvester - AEM10941/HVOUT: C5.1, IC1.14 (HVOUT), TP7.1
/Energy Harvester - AEM10941/LVOUT: C4.1, IC1.11 (LVOUT)
/Energy Harvester - AEM10941/OVCH: IC1.22 (SET_OVCH), R7.2, R8.1
/Energy Harvester - AEM10941/OVDIS: IC1.24 (SET_OVDIS), R5.2, R6.1
/Energy Harvester - AEM10941/PV_cell: C15.1, C16.1, IC1.25 (SRC), IC1.26 (FB_COLD), TP1.1
/Energy Harvester - AEM10941/SELMPP0: IC1.8 (SELMPP[0]), JP7.2 (C)
/Energy Harvester - AEM10941/SELMPP1: IC1.7 (SELMPP[1]), JP6.2 (C)
/Energy Harvester - AEM10941/Vbuck: C2.2, IC1.3 (BUCK), JP3.1 (A), JP4.3 (B), JP5.3 (B), JP6.1 (A), JP7.1 (A), JP8.1 (A), JP9.1 (A), L1.1
/LSB: C17.1, IC1.16 (BATT), IC2.1 (VBAT), IC2.3 (CE), IC2.7 (L1), J3.1
GND: C1.1, C2.1, C3.2, C4.2, C5.2, C6.2, C7.2, C8.2, C9.2, C10.2, C11.2, C12.2, C13.2, C14.2, C15.2, C16.2, C17.2, C18.2, C19.2, D1.1 (A), IC1.9 (FB_PRIM_D), IC1.10 (FB_PRIM_U), IC1.15 (BAL), IC1.17 (PRIM), IC1.29 (EP), IC2.2 (GND_1), IC2.4 (GND_2), IC2.9 (EP_GND), IC3.2 (GND), IC4.6 (VSS_1), IC4.7 (VSS_2), IC4.9 (VSS_3), J1.1, J1.S1 (SHIELD), J1.S2 (SHIELD), J2.A1_B12 (GND), J2.B1_A12 (GND), J3.2, JP3.3 (B), JP4.1 (A), JP5.1 (A), JP6.3 (B), JP7.3 (B), JP8.3 (B), JP9.3 (B), R2.2, R3.2, R8.2, R9.2, S1.2, S2.4 (NO_2), SW2.1, TP2.1, TP13.1, U1.6 (VSS), U2.1 (GND), U2.51 (GND), U2.52 (GND), U2.60 (GND), U2.61 (GND), U2.62 (GND), U2.63 (GND), U2.64 (GND), U2.65 (GND), U2.66 (GND), U2.67 (GND)
unnamed: C3.1, IC1.27 (BUFSRC), L2.1
unnamed: IC1.28 (SWBOOST), L2.2
unnamed: IC1.2 (SWBUCK), L1.2
unnamed: IC2.5 (LX), IC2.8 (L2)
unnamed: IC3.3 (EN), R1.2
unnamed: IC4.11 (RES_N), R12.2
unnamed: J2.A5 (CC1), R9.1
unnamed: J2.B5 (CC2), R3.1
unnamed: J2.S1 (SHELL_GND), J2.S2 (SHELL_GND), J2.S3 (SHELL_GND), J2.S4 (SHELL_GND), R2.1
unnamed: JP1.2 (B), U2.30 (PWR_LED)
VIN: C18.1, IC2.6 (VOUT), JP2.1 (A), U2.20 (VIN(3-5V))

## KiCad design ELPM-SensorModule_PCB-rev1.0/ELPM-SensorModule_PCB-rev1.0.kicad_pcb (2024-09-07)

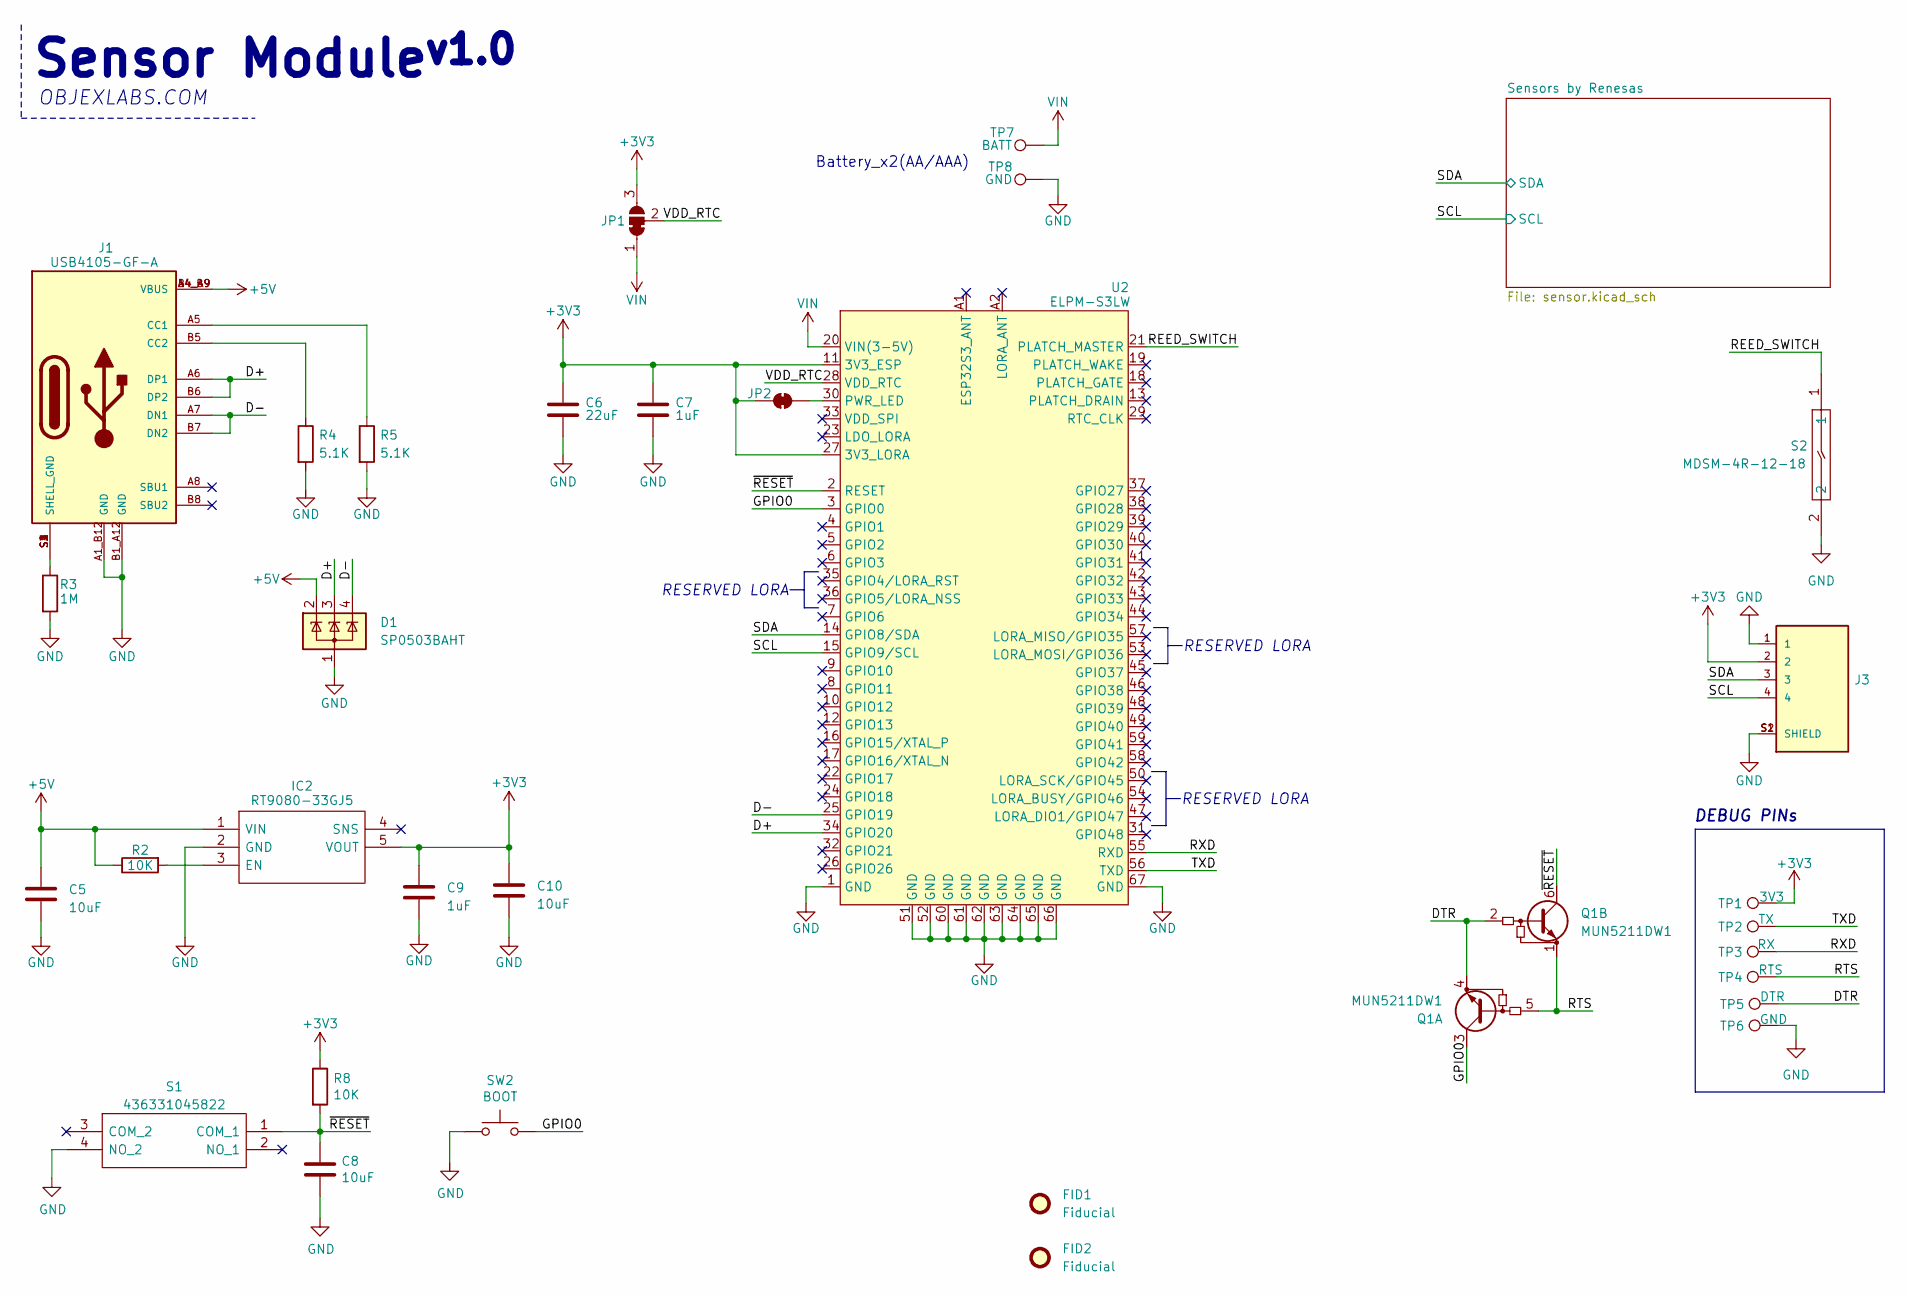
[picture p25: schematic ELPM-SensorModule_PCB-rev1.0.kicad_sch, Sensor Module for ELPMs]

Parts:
C5, C8, C10: 10uF; C_0402_1005Metric
C6: 22uF; C_0603_1608Metric
C7, C9: 1uF; C_0402_1005Metric
D1: SP0503BAHT; SOT-143
FID1, FID2: Fiducial; Fiducial_0.5mm_Mask1mm
IC2: RT9080-33GJ5; SOT94P280X100-5N; Manufacturer_Part_Number RT9080-33GJ5
J1: USB4105-GF-A; GCT_USB4105-GF-A; PARTREV A3
J3: SM04B-SRSS-TB(LF)(SN); JST_SM04B-SRSS-TB(LF)(SN)
JP1: SolderJumper_3_Bridged12; SolderJumper-3_P1.3mm_Bridged12_RoundedPad1.0x1.5mm_NumberL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
JP2: SolderJumper_2_Bridged; SolderJumper-2_P1.3mm_Bridged_RoundedPad1.0x1.5mm
Q1: MUN5211DW1; SOT-363_SC-70-6
R2, R8: 10K; R_0402_1005Metric
R3: 1M; R_0402_1005Metric
R4, R5: 5.1K; R_0402_1005Metric
S1: 436331045822; Mouser Part Number 710-436331045822
S2: MDSM-4R-12-18; MDSM4R1218; Mouser Part Number 934-MDSM-4R12-18
SW2: BOOT; SW_Push_SPST_NO_Alps_SKRK
TP1: 3V3; TestPoint_Pad_D1.5mm
TP2: TX; TestPoint_Pad_D1.5mm
TP3: RX; TestPoint_Pad_D1.5mm
TP4: RTS; TestPoint_Pad_D1.5mm
TP5: DTR; TestPoint_Pad_D1.5mm
TP6: GND; TestPoint_Pad_D1.5mm
TP7: BATT; TestPoint_Pad_2.0x2.0mm
TP8: GND; TestPoint_Pad_2.0x2.0mm
U2: ELPM-S3LW; ELPM-S3XX

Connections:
+3V3: C6.1, C7.1, C9.1, C10.1, IC2.5 (VOUT), J3.2, JP1.3 (B), JP2.1 (A), R8.1, TP1.1, U2.11 (3V3_ESP), U2.27 (3V3_LORA); also elsewhere on the board
+5V: C5.1, D1.2 (K), IC2.1 (VIN), J1.A4_B9 (VBUS), J1.B4_A9 (VBUS), R2.1
/D+: D1.3 (K), J1.A6 (DP1), J1.B6 (DP2), U2.34 (GPIO20)
/D-: D1.4 (K), J1.A7 (DN1), J1.B7 (DN2), U2.25 (GPIO19)
/DTR: Q1.2 (B2), Q1.4 (E1), TP5.1
/GPIO0: Q1.3 (C1), SW2.2, U2.3 (GPIO0)
/REED_SWITCH: S2.1, U2.21 (PLATCH_MASTER)
/RTS: Q1.1 (E2), Q1.5 (B1), TP4.1
/RXD: TP3.1, U2.55 (RXD)
/SCL: J3.4, U2.15 (GPIO9/SCL); also elsewhere on the board
/SDA: J3.3, U2.14 (GPIO8/SDA); also elsewhere on the board
/TXD: TP2.1, U2.56 (TXD)
/VDD_RTC: JP1.2 (C), U2.28 (VDD_RTC)
/~RESET: C8.1, Q1.6 (C2), R8.2, S1.1 (COM_1), U2.2 (RESET)
GND: C5.2, C6.2, C7.2, C8.2, C9.2, C10.2, D1.1 (A), IC2.2 (GND), J1.A1_B12 (GND), J1.B1_A12 (GND), J3.1, J3.S1 (SHIELD), J3.S2 (SHIELD), R3.2, R4.2, R5.2, S1.4 (NO_2), S2.2, SW2.1, TP6.1, TP8.1, U2.1 (GND), U2.51 (GND), U2.52 (GND), U2.60 (GND), U2.61 (GND), U2.62 (GND), U2.63 (GND), U2.64 (GND), U2.65 (GND), U2.66 (GND), U2.67 (GND); also elsewhere on the board
unnamed: IC2.3 (EN), R2.2
unnamed: J1.A5 (CC1), R5.1
unnamed: J1.B5 (CC2), R4.1
unnamed: J1.S1 (SHELL_GND), J1.S2 (SHELL_GND), J1.S3 (SHELL_GND), J1.S4 (SHELL_GND), R3.1
unnamed: JP2.2 (B), U2.30 (PWR_LED)
VIN: JP1.1 (A), TP7.1, U2.20 (VIN(3-5V))

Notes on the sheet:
RESERVED LORA
OBJEXLABS.COM
DEBUG PINs
Sensor Module^{v1.0}
Battery_x2(AA/AAA)

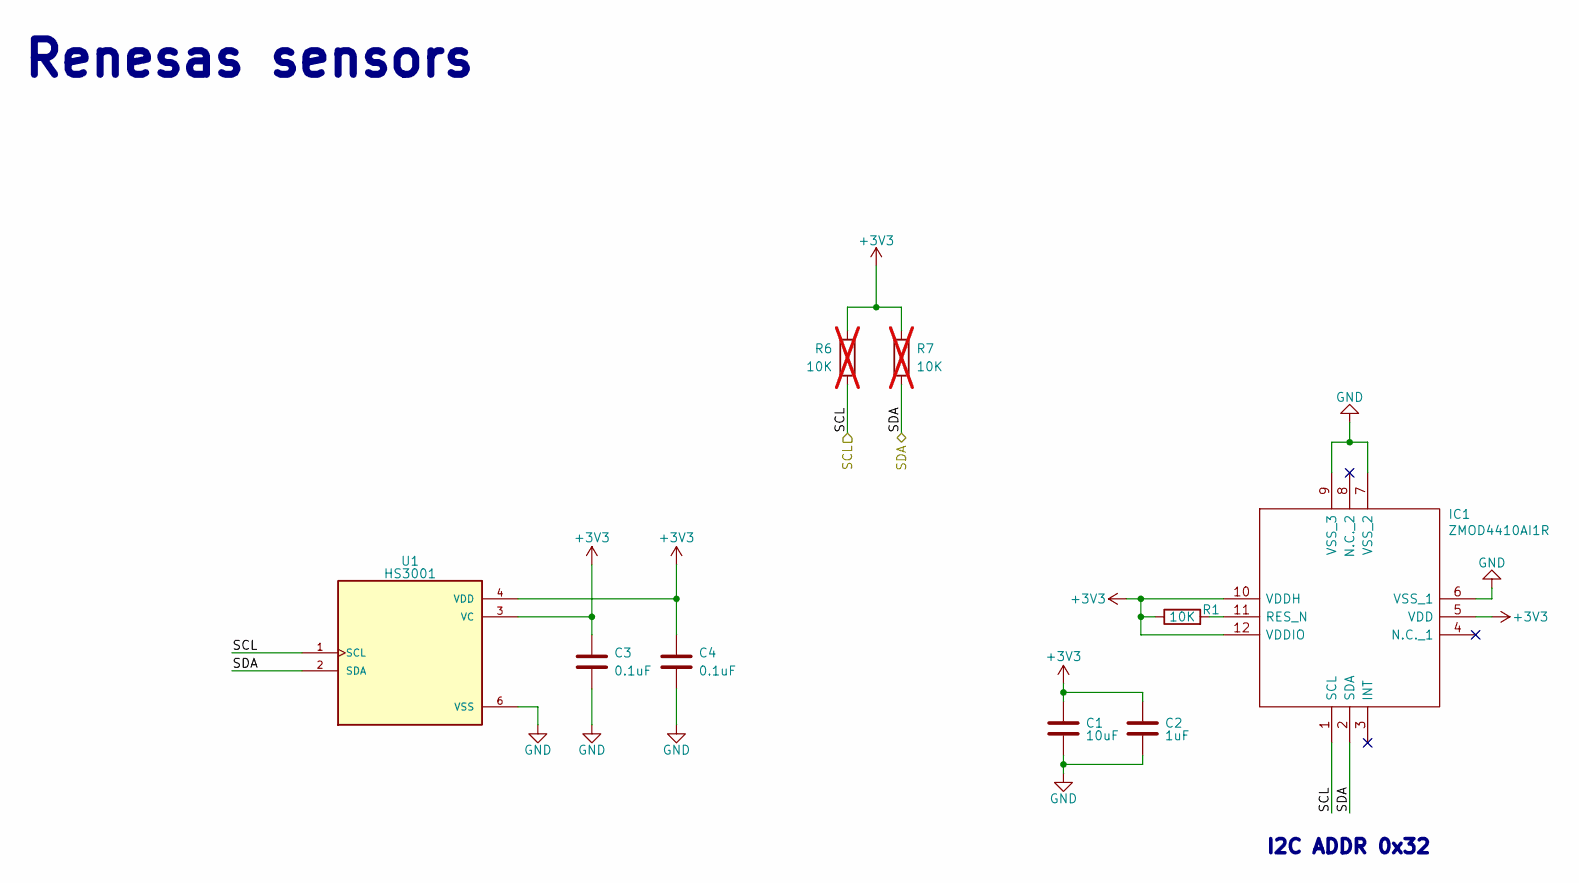
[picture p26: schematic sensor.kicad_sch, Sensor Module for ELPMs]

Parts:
C1: 10uF; C_0402_1005Metric
C2: 1uF; C_0402_1005Metric
C3, C4: 0.1uF; C_0402_1005Metric
IC1: ZMOD4410AI1R; Mouser Part Number 964-ZMOD4410AI1R
R1: 10K; R_0402_1005Metric
R6, R7: 10K; R_0402_1005Metric; not fitted
U1: HS3001; XDCR_HS3001; PARTREV August 6, 2018 (Rev 01)

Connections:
+3V3: C1.1, C2.1, C3.1, C4.1, IC1.5 (VDD), IC1.10 (VDDH), IC1.12 (VDDIO), R1.1, R6.1, R7.1, U1.3 (VC), U1.4 (VDD); also elsewhere on the board
/SCL: IC1.1 (SCL), R6.2, U1.1 (SCL); also elsewhere on the board
/SDA: IC1.2 (SDA), R7.2, U1.2 (SDA); also elsewhere on the board
GND: C1.2, C2.2, C3.2, C4.2, IC1.6 (VSS_1), IC1.7 (VSS_2), IC1.9 (VSS_3), U1.6 (VSS); also elsewhere on the board
unnamed: IC1.11 (RES_N), R1.2

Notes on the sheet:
Renesas sensors
I2C ADDR 0x32

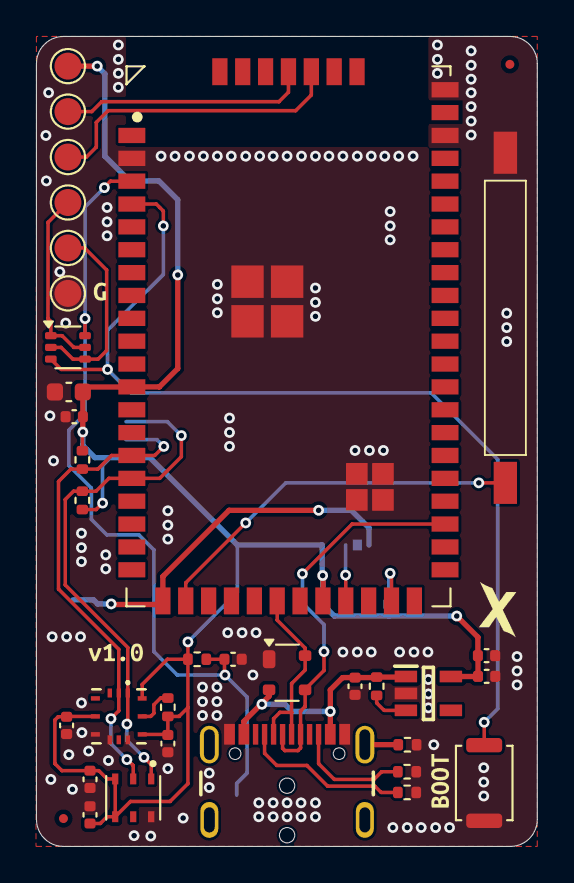
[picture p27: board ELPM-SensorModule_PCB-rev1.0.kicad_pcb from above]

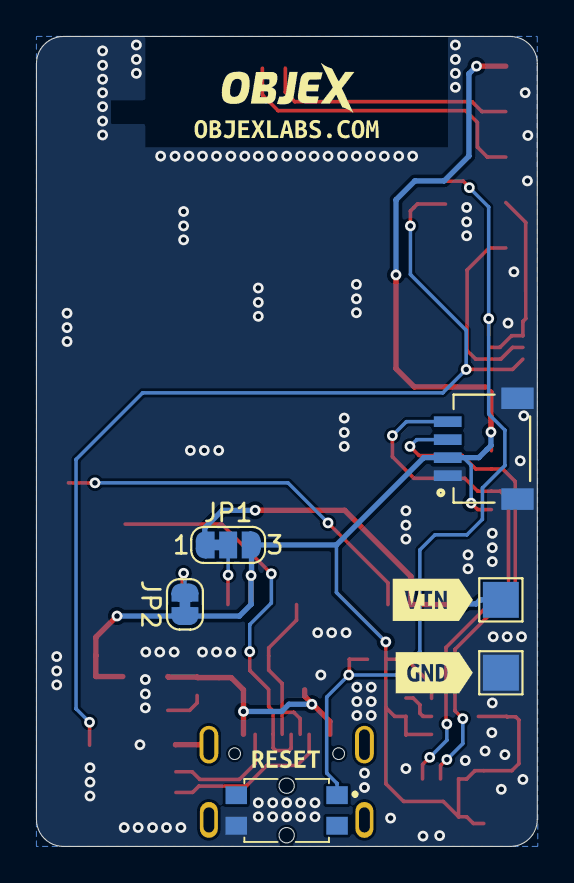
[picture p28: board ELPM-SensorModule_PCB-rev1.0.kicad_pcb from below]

Board: 2 copper layers, 27.8 x 45.0 mm, 48 parts (10 on the bottom side), 22 nets.

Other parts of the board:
kibuzzard-64D611C7: G***; kibuzzard-64D611C7
kibuzzard-6676ECD5: G***; kibuzzard-6676ECD5
kibuzzard-667956CB: G***; kibuzzard-667956CB
kibuzzard-667956E6: G***; kibuzzard-667956E6
kibuzzard-667957A8: G***; kibuzzard-667957A8
kibuzzard-66795660: G***; kibuzzard-66795660
kibuzzard-66795678: G***; kibuzzard-66795678

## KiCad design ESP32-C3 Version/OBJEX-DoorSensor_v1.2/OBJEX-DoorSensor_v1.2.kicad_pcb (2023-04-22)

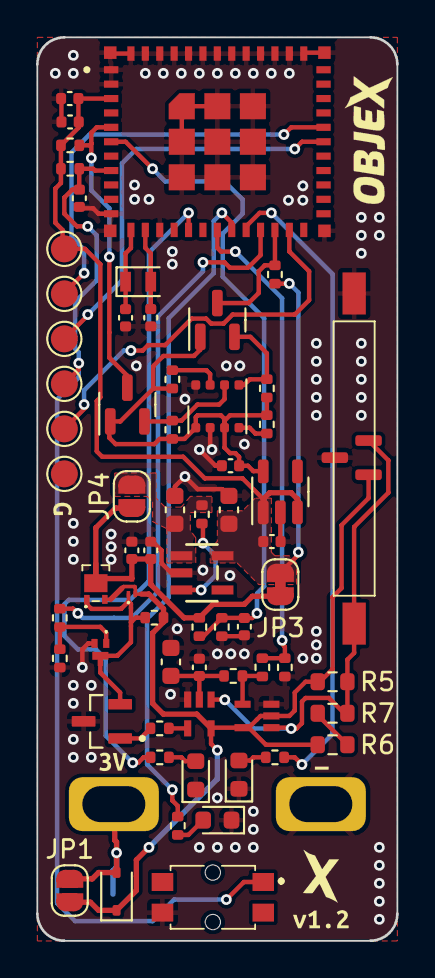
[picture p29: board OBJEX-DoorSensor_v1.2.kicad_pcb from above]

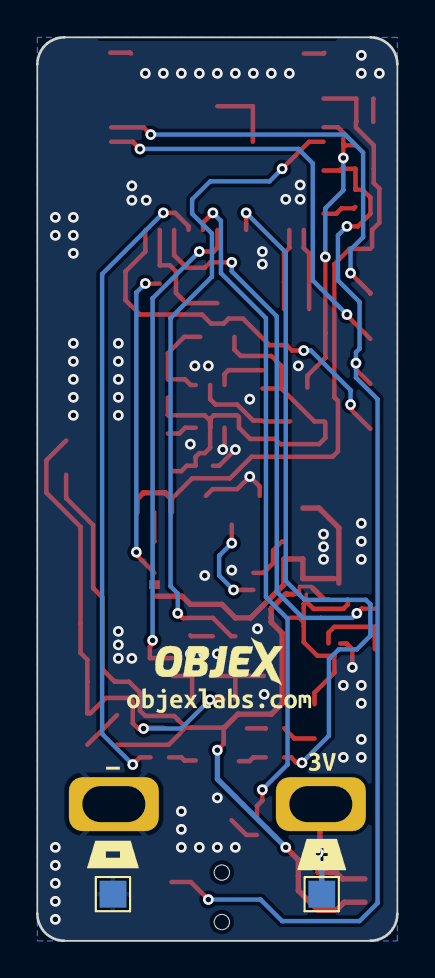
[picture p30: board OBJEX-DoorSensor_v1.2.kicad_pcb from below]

Board: 2 copper layers, 20.0 x 50.2 mm, 79 parts (7 on the bottom side), 37 nets.

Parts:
C1, C4, C9, C12: 10uF; C_0402_1005Metric
C2, C3: 12pF; C_0402_1005Metric
C5: 0.1uF; C_0402_1005Metric
C6: 1uF; C_0603_1608Metric
C7: 1uF/4.7uF; C_0603_1608Metric
C8: 10uF; C_0603_1608Metric
C10, C14, C15: 1uF; C_0402_1005Metric
C11: 10nF; C_0402_1005Metric
D1: RED; LED_0603_1608Metric
D2: GREEN; LED_0603_1608Metric
D3: BLUE; LED_0603_1608Metric
D5: 1N4148WS; D_SOD-323
JP1, JP4: SolderJumper_2_Open; SolderJumper-2_P1.3mm_Open_RoundedPad1.0x1.5mm
JP3: SolderJumper_2_Bridged; SolderJumper-2_P1.3mm_Bridged_RoundedPad1.0x1.5mm
Q1: BC857B_RF; SOT95P237X112-3N
Q2: NTNUS3171PZT5G; ONSC-SOT-1123-3-524AA_V
Q3: 2N7002KQBZ
Q4, Q5: BSS138; SOT-23
Q6: DMG3415UFY4Q-7; DMG3415UFY47
R1, R2, R4, R8, R9, R10, R12, R15, R16, R17, R18, R19: 10K; R_0402_1005Metric
R3, R20, R21, R23: 1K; R_0402_1005Metric
R5: 100M; R_0603_1608Metric
R6, R7: R; R_0603_1608Metric
R11: 1M; R_0402_1005Metric
R13, R22: 100K; R_0402_1005Metric
R14: 150K; R_0402_1005Metric
S1: MDSM-4R-12-18; MDSM4R1218
S2: 436331045822
TP1: BATT; TestPoint_Pad_1.5x1.5mm
TP2: GND; TestPoint_Pad_1.5x1.5mm
TP3: VBUS; TestPoint_Pad_D1.5mm
TP4: TX; TestPoint_Pad_D1.5mm
TP5: RX; TestPoint_Pad_D1.5mm
TP6: RTS; TestPoint_Pad_D1.5mm
TP7: DTR; TestPoint_Pad_D1.5mm
TP8: GND; TestPoint_Pad_D1.5mm
U1: 5204
U2: RT9080-33GJ5; TSOT-23
U3: S-5701BC11B-L3T2U5; S'5701BC11B'L3T2U5
U4, U5: SN74LVC1G86DBVR; SOT353
U6: BME680; Bosch_LGA-8_3x3mm_P0.8mm_ClockwisePinNumbering
U7: ESP32-C3-MINI-1-N4; XCVR_ESP32-C3-MINI-1-N4
U8: MCP1802T-1802I/OT; SOT-23-5
U10: 5226
Y1: Crystal; Crystal_SMD_2012-2Pin_2.0x1.2mm
kibuzzard-63AF0800: G***; kibuzzard-63AF0800
kibuzzard-642BF0F2: G***; kibuzzard-642BF0F2
kibuzzard-642BF081: G***; kibuzzard-642BF081
kibuzzard-64258E17, kibuzzard-64258E17#2: G***; kibuzzard-64258E17
kibuzzard-64258E23, kibuzzard-64258E23#2: G***; kibuzzard-64258E23
kibuzzard-64258E65: G***; kibuzzard-64258E65
kibuzzard-64258FE0: G***; kibuzzard-64258FE0

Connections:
+1V8: C14.1, Q4.1 (G), Q5.1 (G), R15.1, R16.1, R17.1, R18.1, U6.6 (VDDIO), U6.8 (VDD), U8.5 (VOUT)
+3V3: C4.1, C5.1, C7.2, C15.1, JP3.2 (B), R1.1, R2.2, R19.2, TP3.1, U2.5 (VOUT), U7.3 (3V3), U8.1 (VIN), U8.3 (~SHDN)
+BATT: D5.1 (K), JP1.2 (B), Q2.2, Q6.2, R5.1, R6.1, R11.1, U3.2 (VDD), U4.2 (B), U4.5 (VCC), U5.5 (VCC)
/Microcontroller + WiFi-BLE/AUTO_TURN_OFF: R12.2, U7.21 (IO7)
/Microcontroller + WiFi-BLE/BATT_LVL: C11.1, R13.2, R14.1, U7.6 (IO3)
/Microcontroller + WiFi-BLE/DTR/GPIO9: TP7.1, U7.23 (IO9)
/Microcontroller + WiFi-BLE/EN: C1.1, R1.2, S2.1 (COM_1), TP6.1, U7.8 (EN)
/Microcontroller + WiFi-BLE/GPIO0: C2.1, U7.12 (IO0), Y1.1
/Microcontroller + WiFi-BLE/GPIO1: C3.1, U7.13 (IO1), Y1.2
/Microcontroller + WiFi-BLE/GPIO2: Q5.3 (D), R19.1, U7.5 (IO2)
/Microcontroller + WiFi-BLE/GPIO8: Q4.3 (D), R2.1, U7.22 (IO8)
/Microcontroller + WiFi-BLE/IN_STATUS: R8.2, R9.1, U7.18 (IO4)
/Microcontroller + WiFi-BLE/LED_BLUE: R21.2, U7.19 (IO5)
/Microcontroller + WiFi-BLE/LED_GREEN: R20.2, U7.16 (IO10)
/Microcontroller + WiFi-BLE/LED_RED: R3.2, U7.20 (IO6)
/Microcontroller + WiFi-BLE/RX/GPIO20: TP5.1, U7.30 (RXD0)
/Microcontroller + WiFi-BLE/TX/GPIO21: TP4.1, U7.31 (TXD0)
/Power Latch - Rising & falling edge detector /Gate: Q1.2, Q2.1, Q3.3, Q3.4, Q6.1, R11.2
GND: C1.2, C2.2, C3.2, C4.2, C5.2, C6.2, C7.1, C8.2, C9.2, C10.2, C11.2, C12.2, C14.2, C15.2, D1.1 (K), D2.1 (K), D3.1 (K), Q1.3, Q3.2, R9.2, R14.2, R22.2, S1.2, S2.4 (NO_2), TP2.1, TP8.1, U1.1 (-), U2.2 (GND), U3.1 (GND), U4.3 (VEE), U5.3 (VEE), U6.1 (GND), U6.7 (GND), U7.1 (GND), U7.2 (GND), U7.11 (GND), U7.14 (GND), U7.36 (GND), U7.37 (GND), U7.38 (GND), U7.39 (GND), U7.40 (GND), U7.41 (GND), U7.42 (GND), U7.43 (GND), U7.44 (GND), U7.45 (GND), U7.46 (GND), U7.47 (GND), U7.48 (GND), U7.49_1 (GND), U7.49_2 (GND), U7.49_3 (GND), U7.49_4 (GND), U7.49_5 (GND), U7.49_6 (GND), U7.49_7 (GND), U7.49_8 (GND), U7.49_9 (GND), U7.50 (GND), U7.51 (GND), U7.52 (GND), U7.53 (GND), U8.2 (GND)
unnamed: D1.2 (A), R3.1
unnamed: D2.2 (A), R20.1
unnamed: D3.2 (A), R21.1
unnamed: D5.2 (A), JP1.1 (A), TP1.1, U10.1 (+)
unnamed: C9.1, C10.1, JP3.1 (A), JP4.1 (A), Q2.3, Q6.3, R13.1
unnamed: Q1.1, R23.2
unnamed: Q3.1, R12.1, R22.1
unnamed: Q4.2 (S), R18.2, U6.4 (SCK)
unnamed: Q5.2 (S), R17.2, U6.3 (SDI)
unnamed: R6.2, R7.1
unnamed: R4.1, U2.3 (EN)
unnamed: R5.2, R7.2, S1.1, U3.3 (OUT), U4.1 (A), U5.1 (A)
unnamed: R8.1, R10.1, U4.4 (Y)
unnamed: C8.1, C12.1, R10.2, U5.2 (B)
unnamed: R23.1, U5.4 (Y)
unnamed: R16.2, U6.2 (CSB)
unnamed: R15.2, U6.5 (SDO)
VCC: C6.1, JP4.2 (B), R4.2, U2.1 (VIN)

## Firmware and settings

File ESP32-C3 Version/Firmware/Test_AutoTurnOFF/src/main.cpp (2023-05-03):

#include <Arduino.h>

int AUTO_TURN_OFF = 7;

int LED_RED = 6;
int LED_GREEN = 10;
int LED_BLUE = 5;

int IN_STATUS = 4;

void setup() {
  Serial.begin(115200);

  pinMode(AUTO_TURN_OFF, OUTPUT);
  digitalWrite(AUTO_TURN_OFF, HIGH);

  pinMode(LED_RED, OUTPUT);
  pinMode(LED_GREEN, OUTPUT);
  pinMode(LED_BLUE, OUTPUT);

  Serial.println("AUTO TURN OFF");
}

void loop() {
  digitalWrite(LED_RED, HIGH);
  digitalWrite(AUTO_TURN_OFF, HIGH);
  delay(5000);
  Serial.println("SLEEP");
  digitalWrite(LED_RED, LOW);
  digitalWrite(AUTO_TURN_OFF,LOW);
}

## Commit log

2023-03-24 SCH complate
    [BME680.kicad_sch, OBJEX-DoorSensor_v1.2.kicad_sch, PowerLatch.kicad_sch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]
2023-03-27 Ready for components placing
    [OBJEX-DoorSensor_v1.2.kicad_pcb, OBJEX-DoorSensor_v1.2.kicad_sch, PowerLatch.kicad_sch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]
2023-03-30 Start PCB design
    [OBJEX-DoorSensor_v1.2.kicad_pcb, OBJEX-DoorSensor_v1.2.kicad_sch]
2023-04-04 Ready for last review
    [OBJEX-DoorSensor_v1.2.kicad_pcb]
2023-04-05 last review
    [OBJEX-DoorSensor_v1.2.kicad_pcb, OBJEX-DoorSensor_v1.2.kicad_sch]
2023-04-06 Ready for order
    [OBJEX-DoorSensor_v1.2-B_Cu.gbl, OBJEX-DoorSensor_v1.2-B_Mask.gbs, OBJEX-DoorSensor_v1.2-B_Paste.gbp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]
2023-04-07 Final review - ready for production
    [OBJEX-DoorSensor_v1.2-B_Cu.gbl, OBJEX-DoorSensor_v1.2-B_Mask.gbs, OBJEX-DoorSensor_v1.2-B_Paste.gbp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]
2023-04-25 bug fix
    [OBJEX-DoorSensor_v1.2.kicad_sch]
2024-09-07 update, new version
    [AEM10941.kicad_sch, BME680.kicad_sch, Bottom Magnet.stl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]

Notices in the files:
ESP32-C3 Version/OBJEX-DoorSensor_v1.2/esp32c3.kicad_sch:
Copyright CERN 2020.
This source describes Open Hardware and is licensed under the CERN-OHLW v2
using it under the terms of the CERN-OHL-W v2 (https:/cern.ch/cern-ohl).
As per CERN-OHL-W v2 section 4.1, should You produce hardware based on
